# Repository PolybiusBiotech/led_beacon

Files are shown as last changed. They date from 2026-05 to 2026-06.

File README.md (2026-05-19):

# 🚨 LED Beacon 🚨

Upgrading cheap LED beacons for professional DMX/Art-Net stage control.

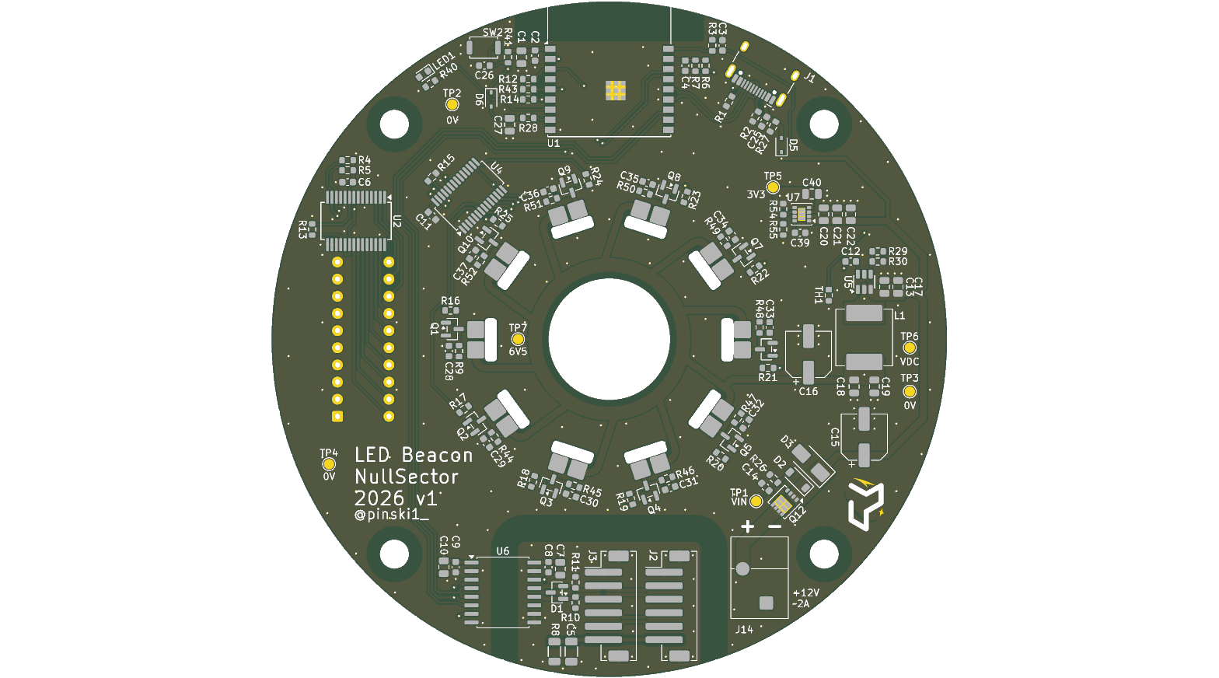
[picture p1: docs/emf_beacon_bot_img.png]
Hardware Render - Bottom


## 🚀 Manufacturing Status
- **Design:** Completed
- **Prototyping:** In Progress
- **Production:** Pending

## 📋 Quick Specs
- **Power:** +12V ±30% @ 2A
- **LEDS:** 10x strings of 6 LEDs
- **MCU:** ESP32-C3-WROOM-02
- **Connectivity:** DMX512 via 5 pin XLRs and WiFi

## 📂 Project Structure
- `/hardware`: KiCAD project files (Version 9.0.7).
- `/firmware`: PlatformIO project (Arduino/ESP-IDF framework).
- `/mechanical`: 3D-printable housing (.STEP).
- `/docs`: Specification, schematics and design calculations.
<!-- test: for test scripts -->

## 🛠 Setup & Development

### Hardware
- **Library Dependencies:** All footprints/symbols are [local to the repo / use standard KiCAD libs].
- **CI/CD:** Schematics are automatically exported to `/docs` on every push.

### Firmware
1. Open the `/firmware` folder in **VS Code**.
2. Ensure the **PlatformIO** extension is installed.
3. Connect your hardware via USB C port and click **Upload**.

## 📝 User Guide

1. Apply power via DC connector, 12V ±30% from a 3A capable supply.
2. Attach to DMX chain with 2x XLR 5pin cables
   * If at the end of the bus use a terminator plug
3. Select a DMX address with the DIP switch
   * This light consumes 20 slots so avoid address above 492.
   * Ensure that this light is >20 slots away from the next lights.
4. Disable the WiFi AP with the DIP switch unless needed for diagnostics
5. Use your DMX controller to send packets on the DMX chain.
   * Slots 1 to 10 control the brightness per channel
     * `0x00` is off
     * `0xFF` is on
   * Slots 11 to 20 control the strobe effect per channel
     * `0x00` is fully on
     * `0x01` strobes at 0.2Hz
     * `0xFF` strobes at 20Hz
6. Enjoy!

---
*Commissioned for Null Sector for EMF Camp 2026.*

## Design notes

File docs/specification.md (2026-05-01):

# LED Beacon: Technical Specification

The goal is to create a PCB that allows cheap LED Beacons to be upgraded so they can be controlled with a typical stage lighting desk.

Using the [MoSCoW method](https://en.wikipedia.org/wiki/MoSCoW_method) to prioritise specifications.

## 1. Must Have
*   **10-Channel Control:** Independent PWM control for 10x 6.4V @ 0.3A LED strips.
*   **DMX512-A Input:** 5-pin XLR interface with 5kV galvanic isolation and TVS protection.
*   **Robust Power Input:** Operation between +12V DC ±30% (8.4V – 15.6V).
*   **Strobe Functionality:** Support for 0.2Hz to 20Hz strobe speeds via DMX512.
    *   `0x00`: Static ON
    *   `0x01`: 0.2Hz Strobe.
    *   `0xFF`: 30Hz Strobe.
*   **Gamma Correction:** Implementation of a gamma brightness curve for human-eye linearity of LED PWM.
*   **Weatherproof Connections:** IP65/67 connectors suitable for outdoor festival use.

## 2. Should Have
*   **ESP32 Core:** Use of an ESP32 microcontroller for primary logic and timing.
*   **Fail-Safe Biasing:** Hardware biasing to ensure the DMX bus stays in a known state if the signal is lost.
*   **Isolation:** 5kV Galvanic Isolation between DMX bus and logic.
*   **Protection:** TVS Diode arrays on all data lines.
*   **Stability:** Active fail-safe biasing to prevent flickering on floating data lines.
*   **JLC-Optimized BOM:** Design utilizing "Basic" parts from the JLCPCB library to meet a £15-20 per unit (in batches of 25x) target.
*   **Enclosure:** Make use of the original beacons parts as much as possible.
*   **Thermal:** Designed for passive cooling at 100% duty cycle across all channels.

## 3. Could Have
*   **Art-Net Support:** Connectivity via RJ45 (Ethernet) to allow for modern lighting network integration.
*   **OTA Updates:** Ability to update firmware over Wi-Fi for last-minute festival bug fixes.
*   **On-board Thermal Monitoring:** Using the ESP32 internal sensor or a dedicated NTC to monitor the PCBA temperature during high-intensity strobe sequences.
*   **Enclosure:** Replace parts of the beacon with custom parts to aid assembly and robustness.
*   **Web Configuration Portal:** An ESP32-hosted captive portal to set DMX start addresses or Art-Net universes without reflashing.
*   **RDM Support:** Remote Device Management over the DMX line for remote addressing.

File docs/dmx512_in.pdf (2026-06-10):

X
Neutrik REAN: RRX5M-Z-002-0
XLR 5way | Pins
GND | 1
DMX+

2
DMX- | 3
AUX- | 4
AUX+ | 5
SHIELD | 6
Additional components
6 x #10 (heatshrink)

W
6x | 26 AWG | 10.0 cm
X:1:GND BK | J:1:GND
X:2:DMX+ RD | J:2:DMX+
X:3:DMX- WH | J:3:DMX-
X:4:AUX- YE | J:4:AUX-
X:5:AUX+ OG | J:5:AUX+
X:6:SHIELD GN | J:6:SHIELD

J
JST: PHR-6
JST PH 6way | Housing | 6-pin 1 | GND 2 | DMX+ 3 | DMX- 4 | AUX- 5 | AUX+ 6 | SHIELD

Additional components
6 x #3 (Crimp)

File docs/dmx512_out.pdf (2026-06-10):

X
Neutrik REAN: RRX5F-Z-002-0
XLR 5way | Socket
GND | 1
DMX+

2
DMX- | 3
AUX- | 4
AUX+ | 5
Additional components
5 x #9 (heatshrink)

W
5x | 26 AWG | 10.0 cm
X:1:GND BK | J:1:GND
X:2:DMX+ RD | J:2:DMX+
X:3:DMX- WH | J:3:DMX-
X:4:AUX- YE | J:4:AUX-
X:5:AUX+ OG | J:5:AUX+

J
JST: PHR-6
JST PH 6way | Housing | 6-pin 1 | GND 2 | DMX+ 3 | DMX- 4 | AUX- 5 | AUX+ 6 | NC

Additional components
5 x #3 (Crimp)

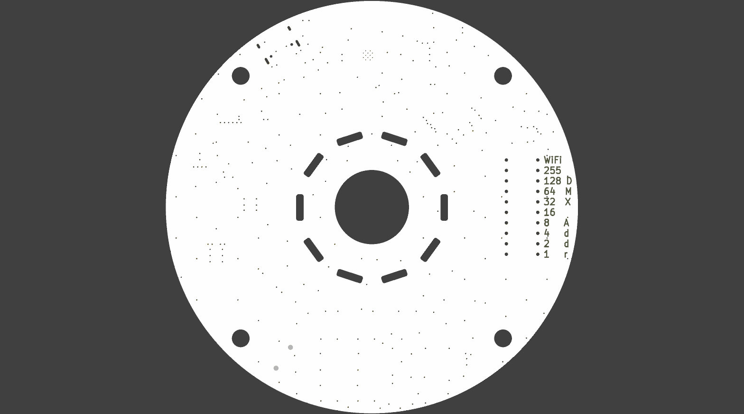
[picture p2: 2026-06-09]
docs/emf_beacon_top_img.png

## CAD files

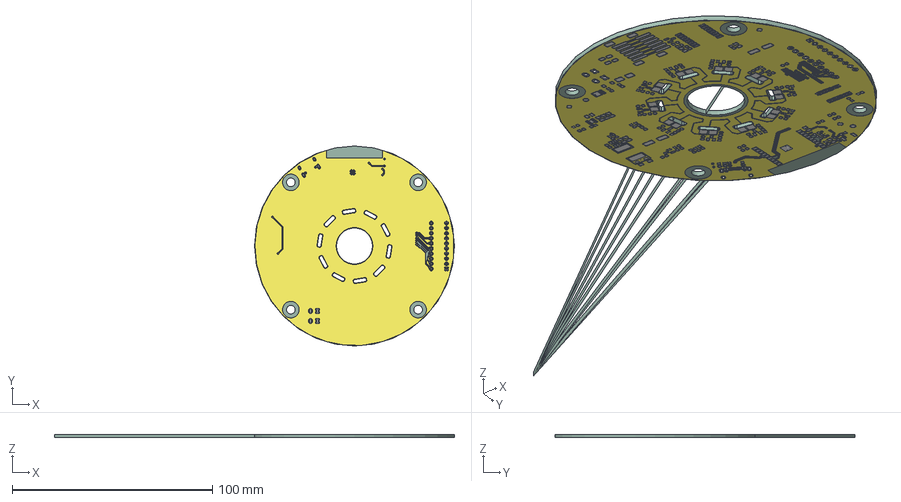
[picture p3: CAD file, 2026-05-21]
docs/emf_beacon_3d.step
200.0 x 150.0 x 1.59 mm
emf_beacon_copper
emf_beacon_pad
emf_beacon_via
emf_beacon_PCB

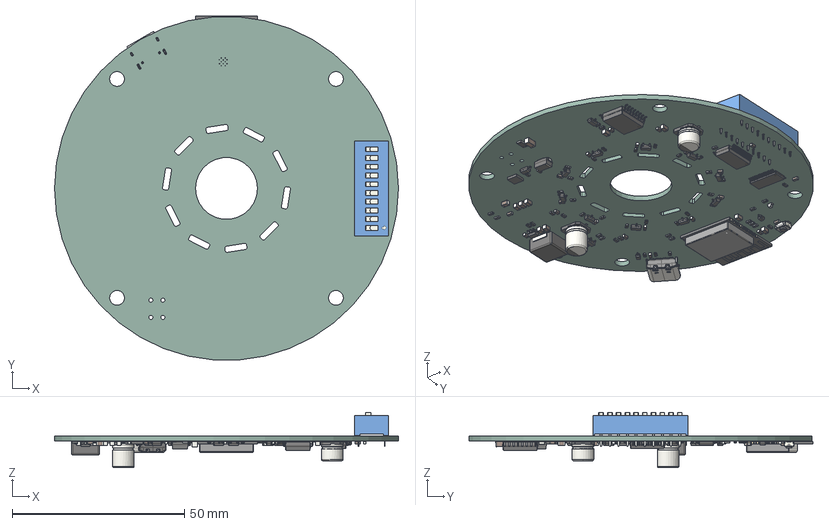
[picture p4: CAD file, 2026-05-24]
hardware/emf_beacon_2025-05-23.step
100.0 x 100.0 x 16.1 mm
SW_DIP_SPSTx10_Slide_9.78x27.58mm_W7.62mm_P2.54mm
C_0805_2012Metric x 12
R_0603_1608Metric x 47
SOIC-16W_7.5x10.3mm_P1.27mm
SOT-23 x 12
C_0603_1608Metric x 22
LED_0603_1608Metric
ESP32-C3-WROOM-02
L_Vishay_IHLP-3232
D_SOD-323 x 2
CP_Elec_6.3x7.7
SW_Push_SPST_NO_Alps_SKRK
SOT-23-6
R_1206_3216Metric
CP_Elec_6.3x5.7
USB_C_Receptacle_GCT_USB4105-xx-A_16P_TopMnt_Horizontal
C_1206_3216Metric
D_SMA
SSOP-28_5.3x10.2mm_P0.65mm
Diodes_PowerDI3333-8
TSSOP-28_4.4x9.7mm_P0.65mm
D_SOD-123
emf_beacon_PCB

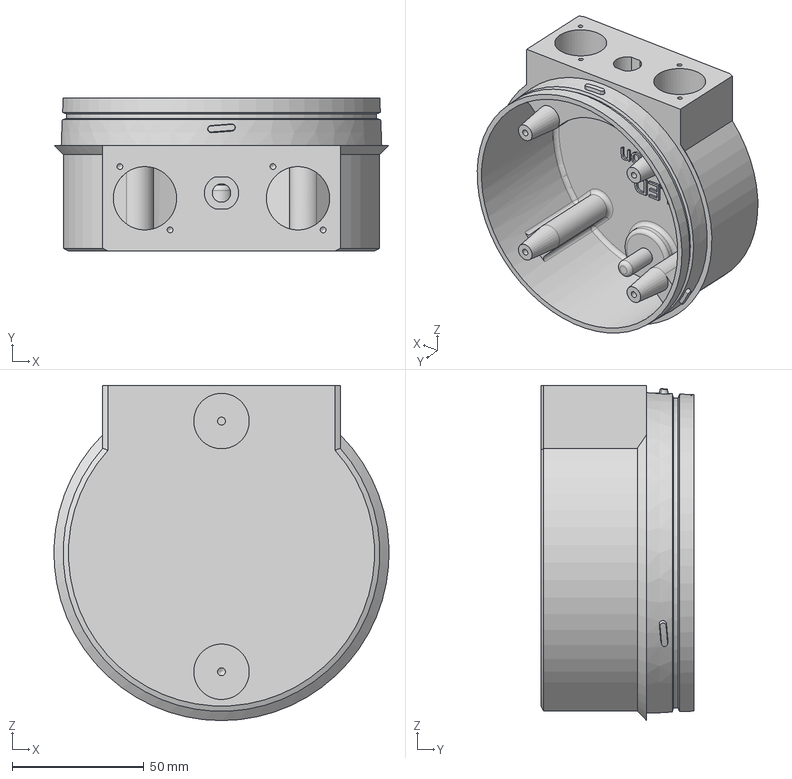
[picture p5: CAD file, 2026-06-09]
mechanical/3D Printed Base v17.step
126.9 x 58.0 x 127.0 mm

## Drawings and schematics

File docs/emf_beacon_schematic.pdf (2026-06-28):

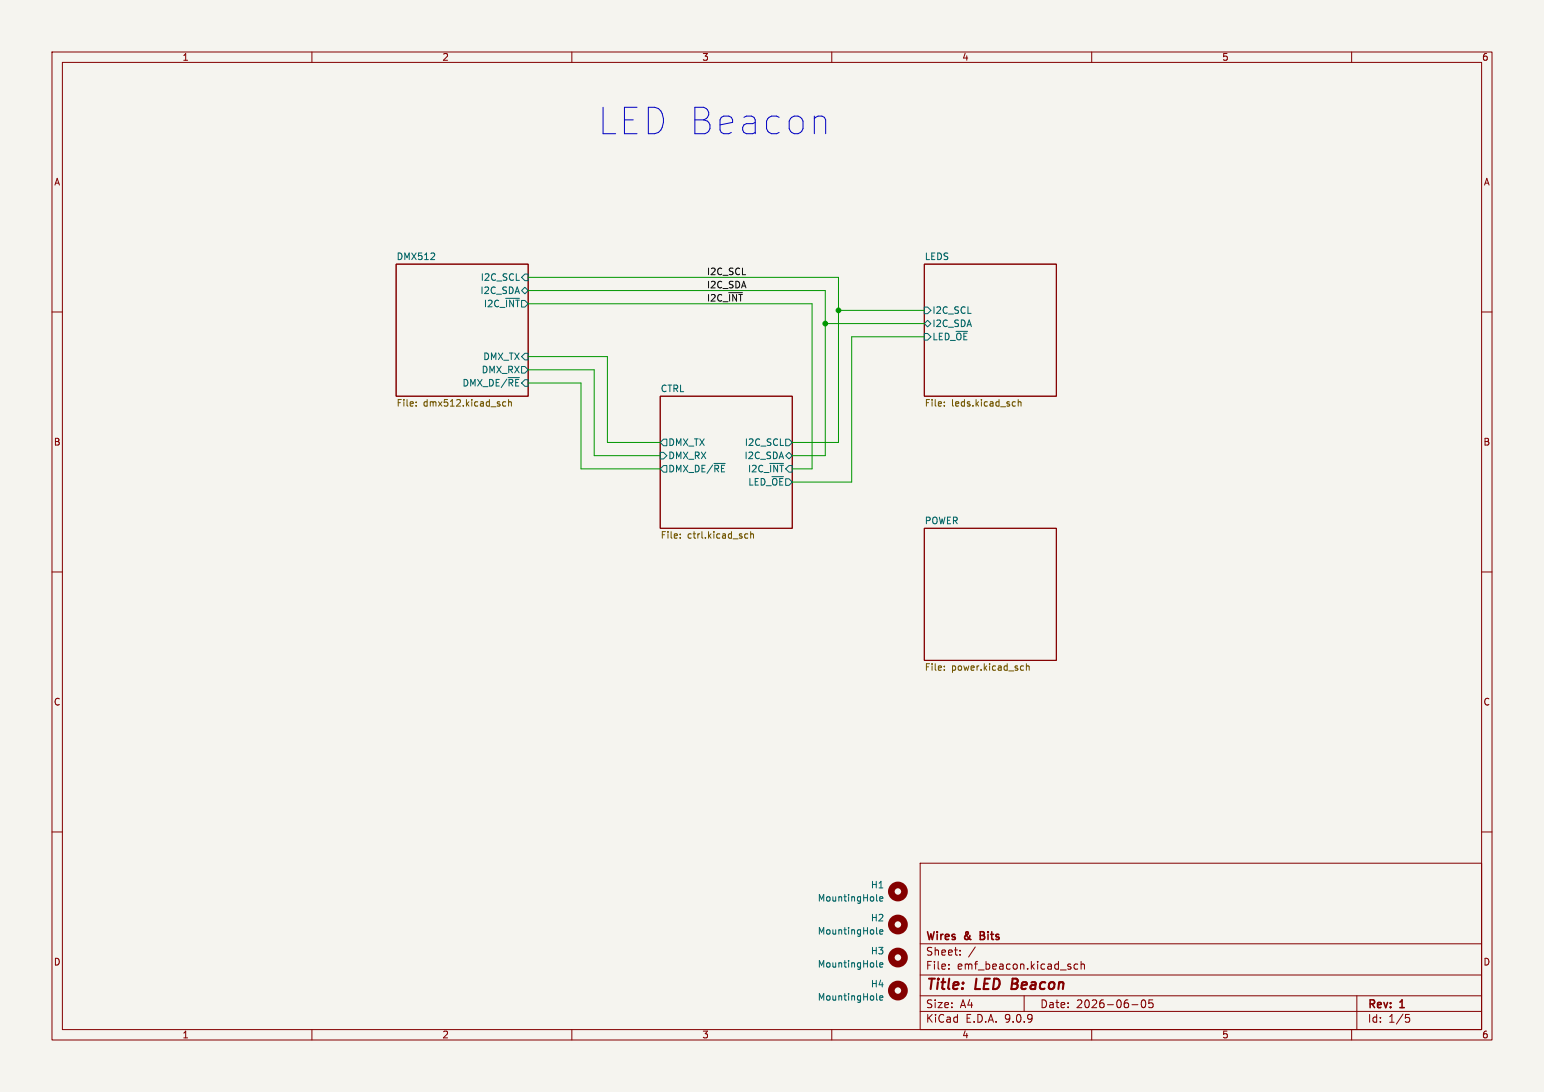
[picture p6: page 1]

Id: 1/5 Title: LED Beacon

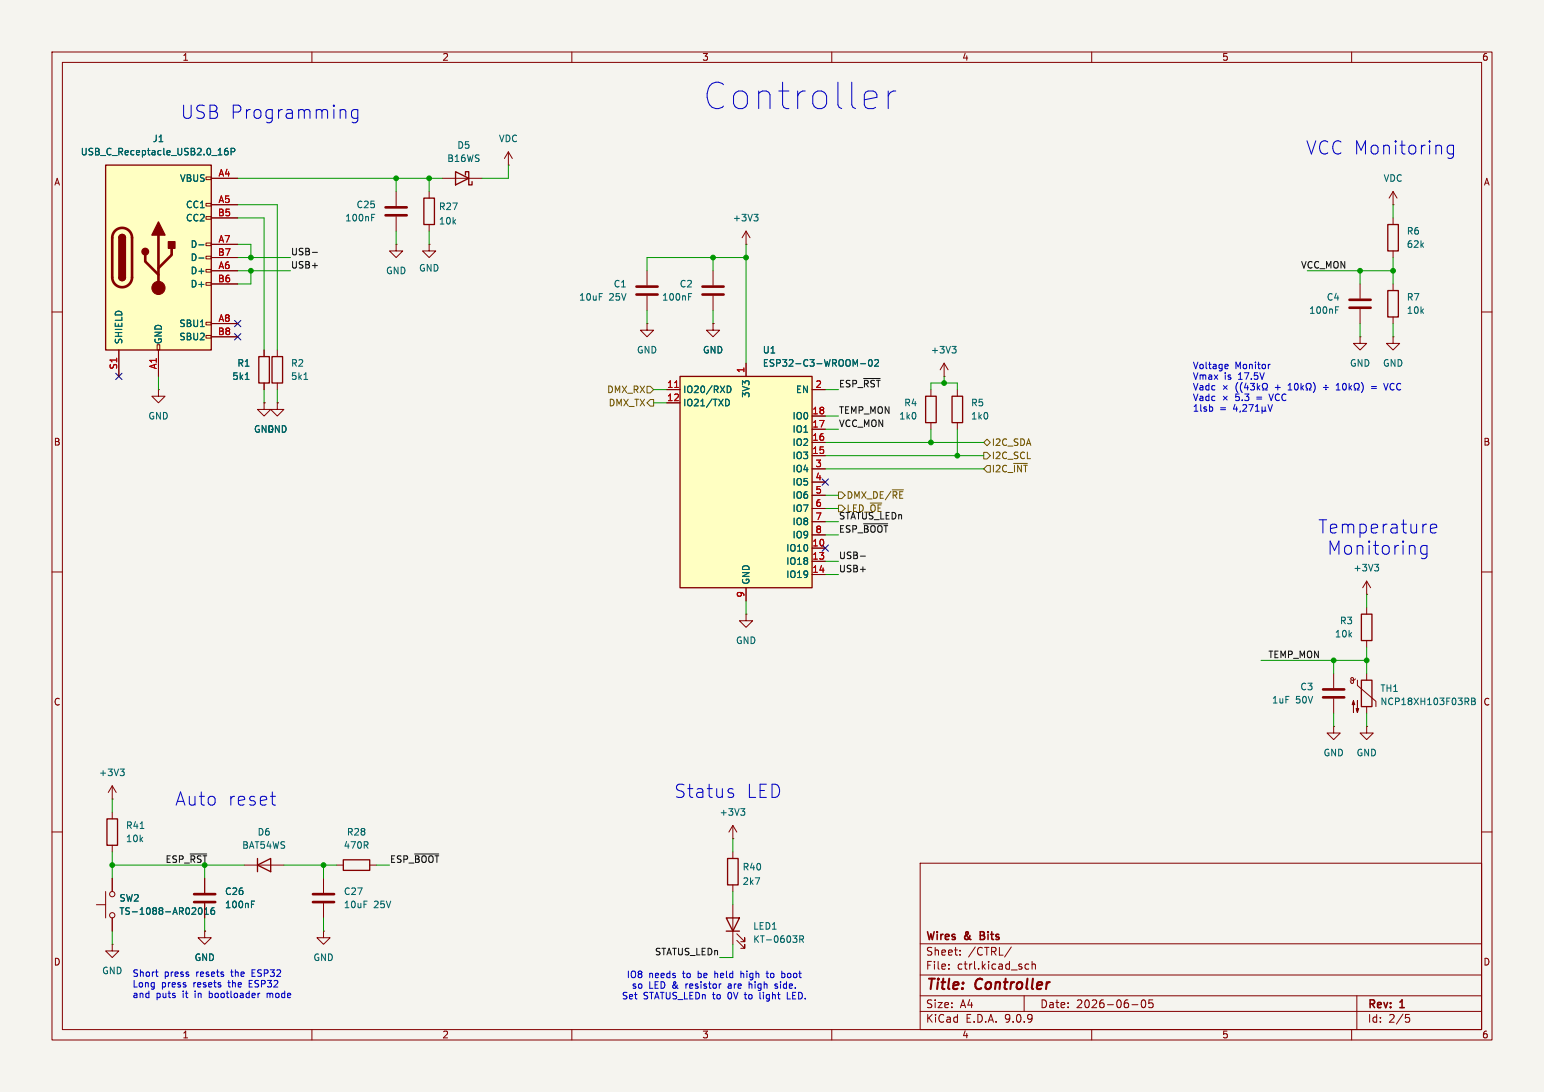
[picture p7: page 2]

Voltage Monitor Vmax is 17.5V

Vadc þÿ×þÿ((43k©+ þÿ10k©) þÿ÷þÿ10k©) = VCC
Vadc þÿ×5.3 = VCC
1lsb = þÿ4,271¼V

Short press resets the ESP32
Long press resets the ESP32

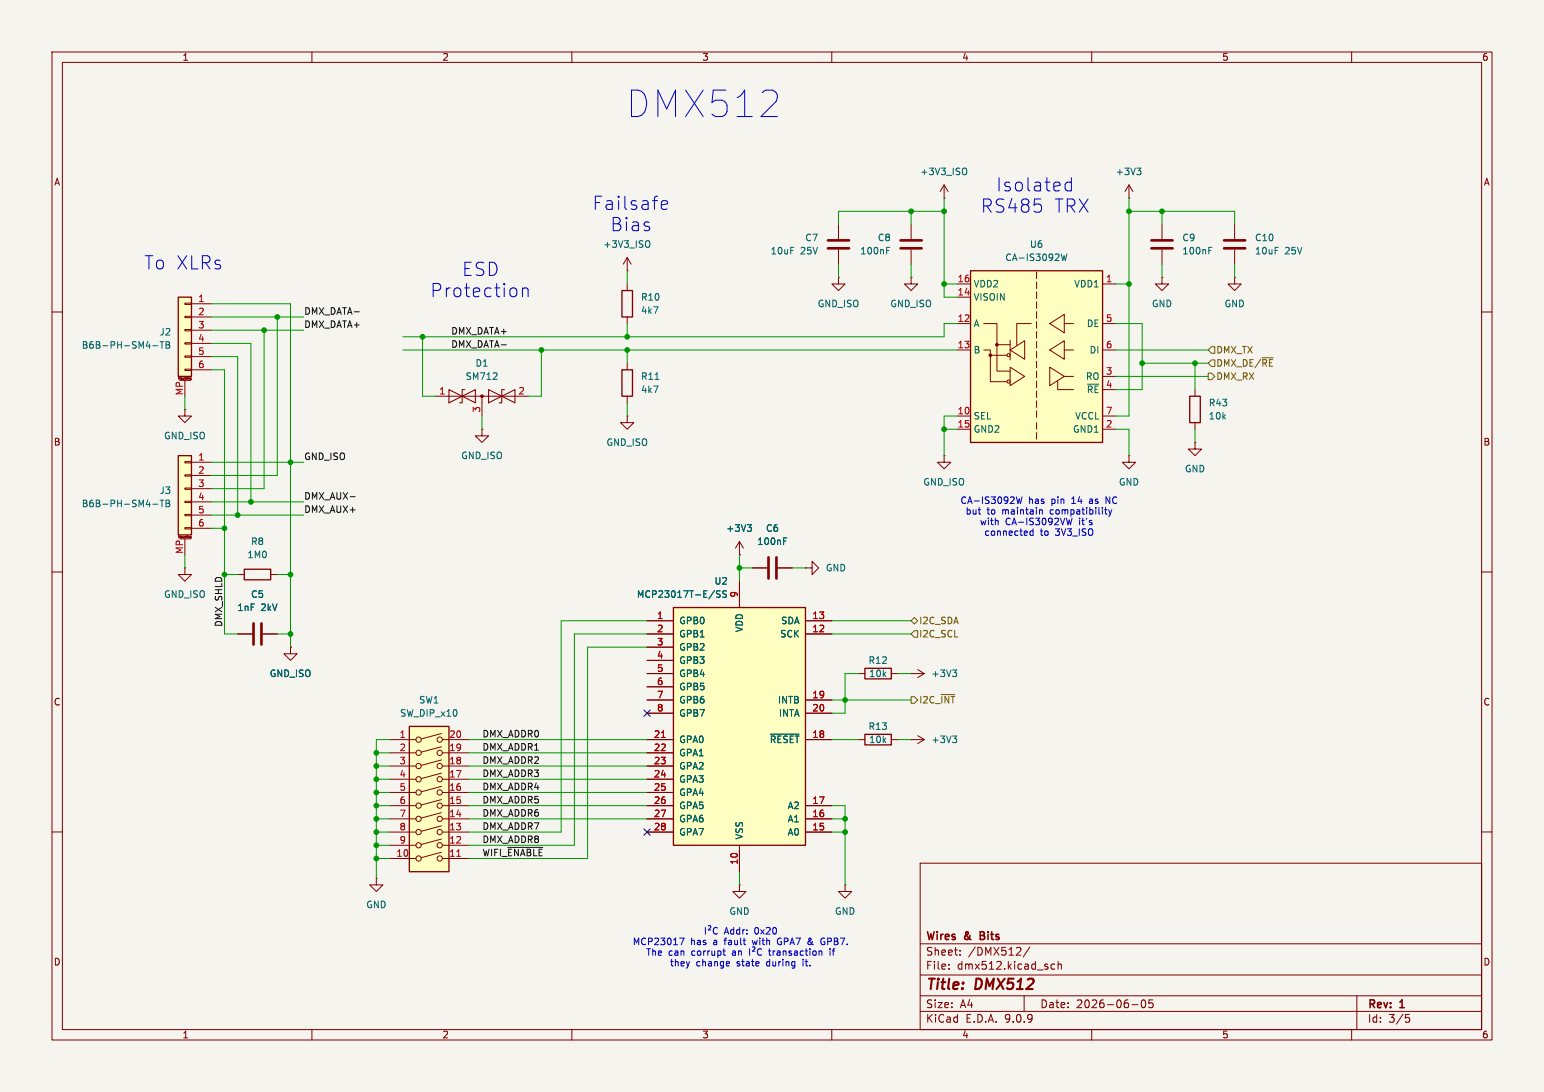
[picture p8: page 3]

they change state during it. Failsafe
Bias

9 VSS 10 GPB0 1 GPB1 2 GPB2 3 GPB3 4 GPB4 5 GPB5 6 GPB6 7 GPB7 8 GPA0 21 GPA1 22 GPA2 23 GPA3 24 GPA4 25 GPA5 26 GPA6 27 GPA7 28 U2 MCP23017T-E/SS GND GND

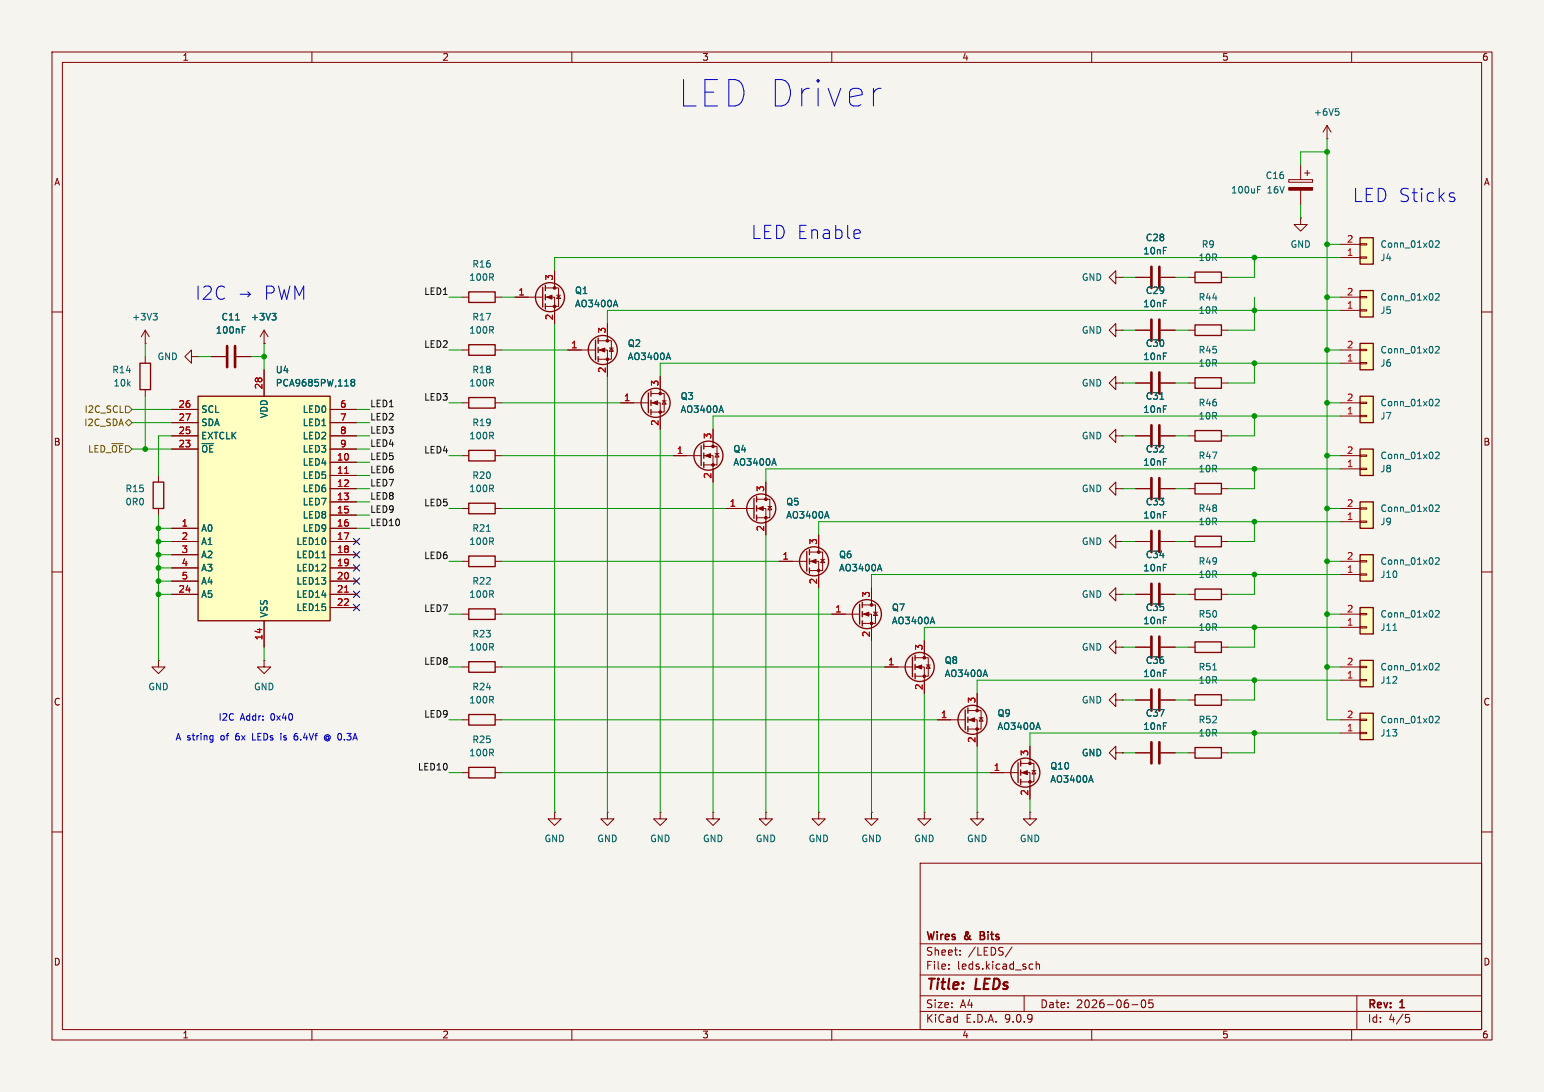
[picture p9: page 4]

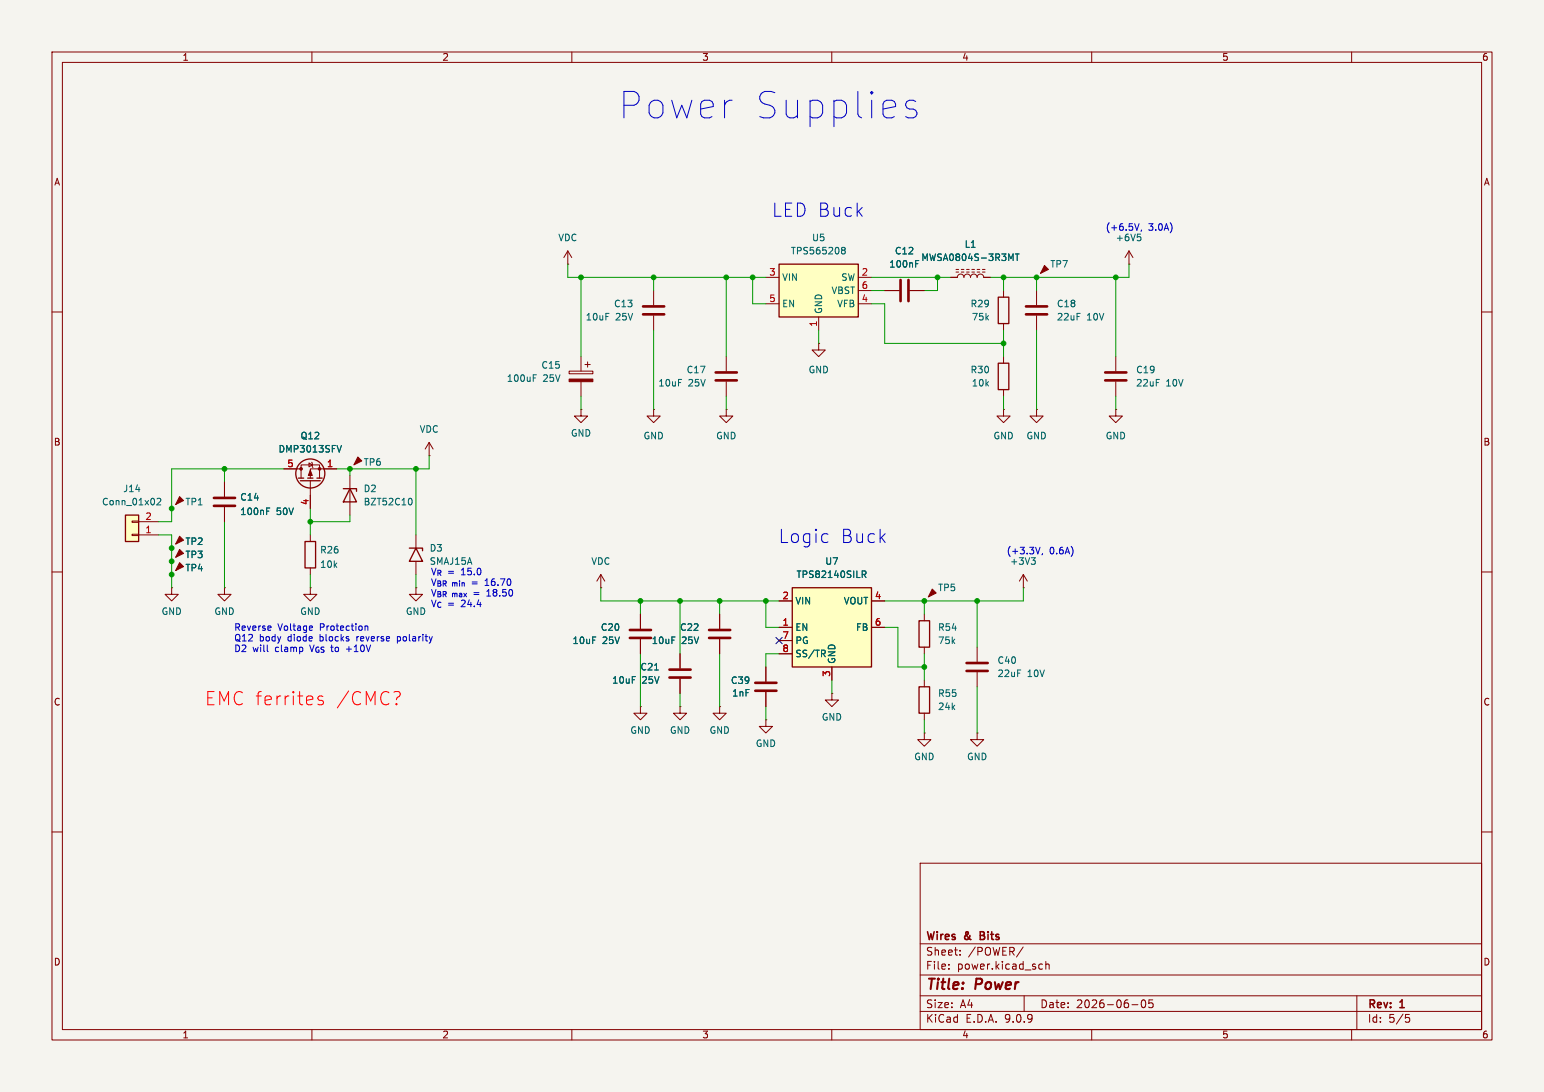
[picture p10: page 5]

1 SW 2 VBST 6 VFB 4 U5 TPS565208 GND GND

V_{R}= 15.0 V_{BR min} = 16.70 V_{BR max} = 18.50 V_{C}= 24.4

Reverse Voltage Protection Q12 body diode blocks reverse polarity D2 will clamp V_{GS} to +10V

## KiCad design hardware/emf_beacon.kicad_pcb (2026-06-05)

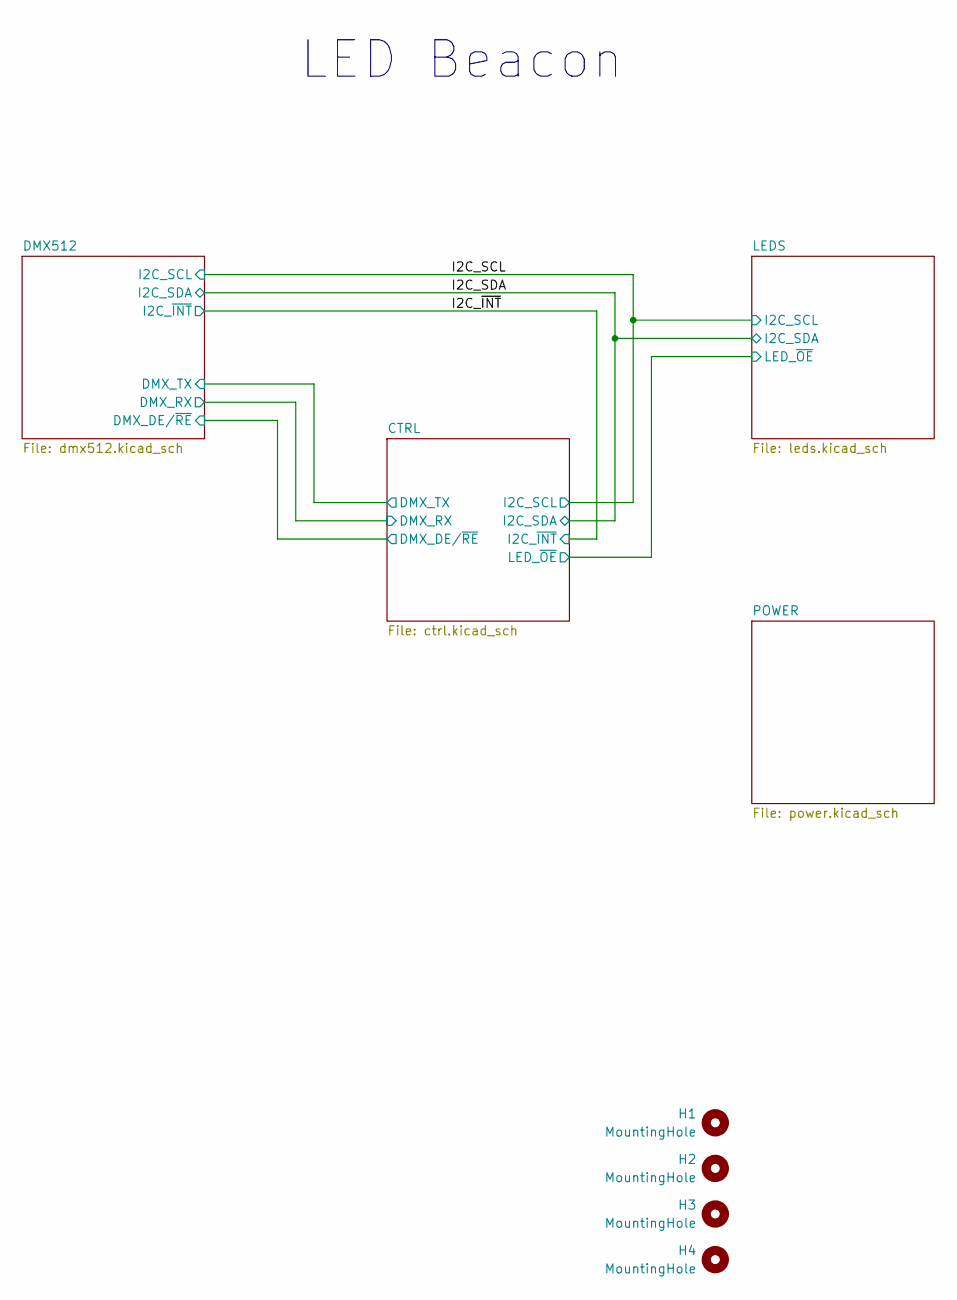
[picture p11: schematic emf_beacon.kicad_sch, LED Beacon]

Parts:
H1, H2, H3, H4: MountingHole; MountingHole_4.3mm_M4

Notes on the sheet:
LED Beacon

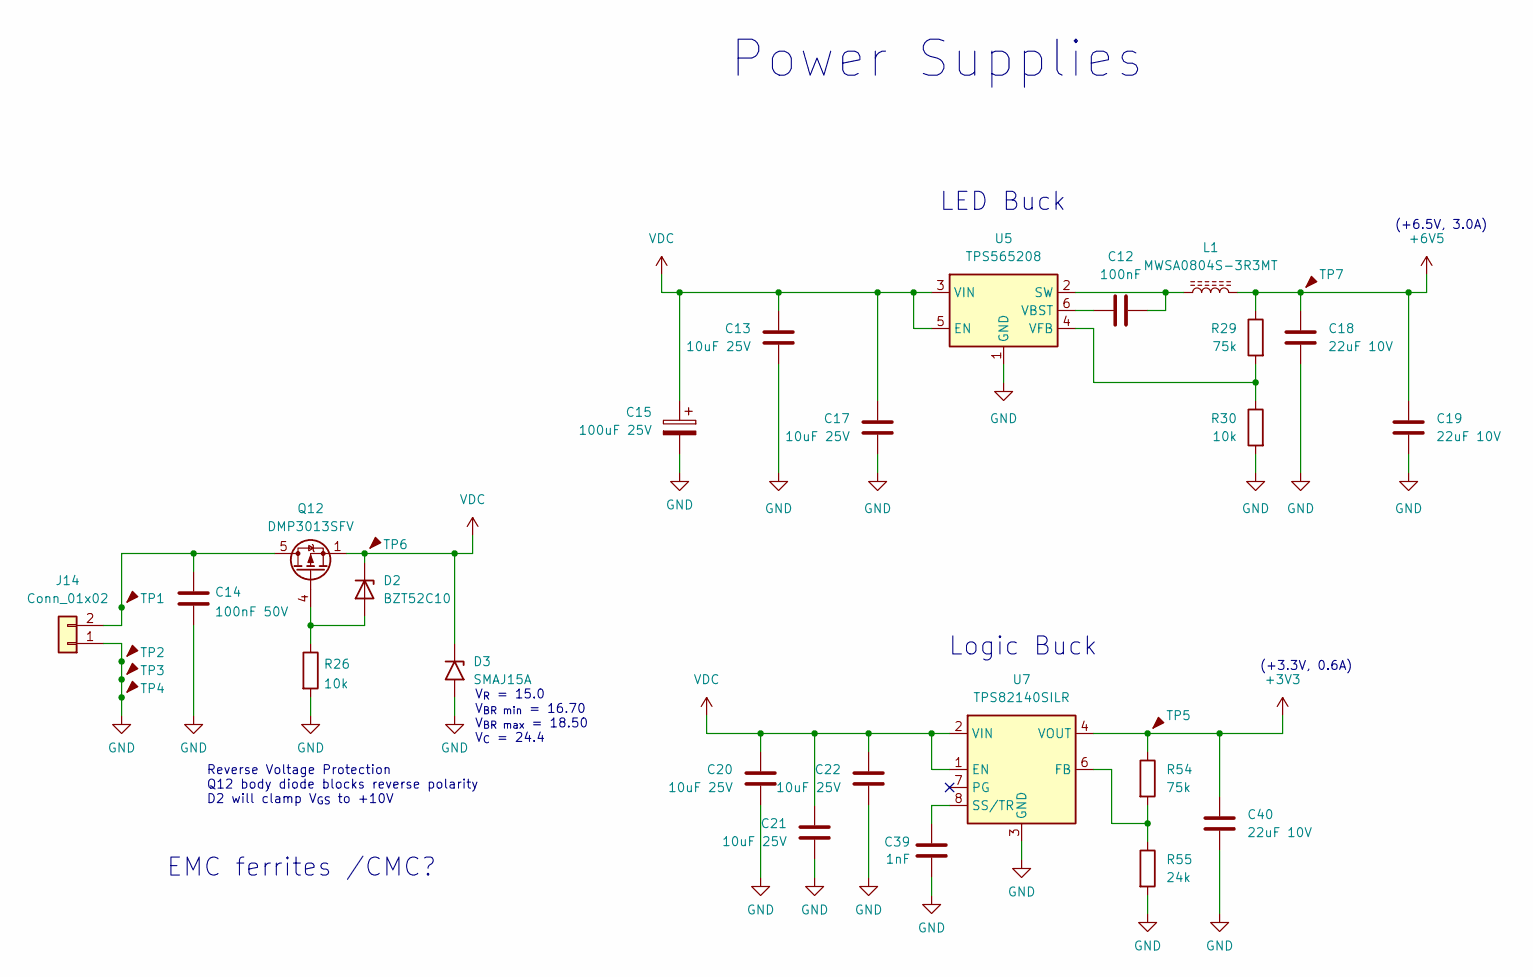
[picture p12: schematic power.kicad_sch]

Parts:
C12: 100nF; C_0603_1608Metric; LCSC C14663
C13, C17, C20, C21, C22: 10uF 25V; C_0805_2012Metric; LCSC C15850
C14: 100nF 50V; C_0603_1608Metric; LCSC C14663
C15: 100uF 25V; CP_Elec_6.3x7.7; LCSC C267469
C18, C19: 22uF 10V; C_0805_2012Metric; LCSC C45783
C39: 1nF; C_0603_1608Metric; Voltage 50V; LCSC C1588
C40: 22uF 10V; C_0805_2012Metric; Voltage 10V; LCSC C45783
D2: BZT52C10; D_SOD-123; LCSC C19077408
D3: SMAJ15A; D_SMA; LCSC C19077535
J14: Conn_01x02; MX250-3.5-02P-A-GY01-Cu-A; LCSC C7467028
L1: MWSA0804S-3R3MT; L_Vishay_IHLP-3232; LCSC C17700166
Q12: DMP3013SFV; Diodes_PowerDI3333-8; LCSC C49452326
R26, R30: 10k; R_0603_1608Metric; LCSC C25804
R29, R54: 75k; R_0603_1608Metric; LCSC C23242
R55: 24k; R_0603_1608Metric; LCSC C23352
TP1, TP2, TP3, TP4, TP5, TP6, TP7: TestPoint; TestPoint_Pad_D1.5mm
U5: TPS565208; SOT-23-6; LCSC C2650336
U7: TPS82140SILR; Texas_SIL0008D_MicroSiP-8-1EP_2.8x3mm_P0.65mm_EP1.1x1.9mm; LCSC C544385

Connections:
+3V3: C40.1, R54.1, TP5.1, U7.4 (VOUT), U7.5 (VOUT); also elsewhere on the board
+6V5: C18.1, C19.1, L1.2, R29.1, TP7.1; also elsewhere on the board
GND: C13.2, C14.2, C15.2, C17.2, C18.2, C19.2, C20.2, C21.2, C22.2, C39.2, C40.2, D3.2 (A2), J14.1, R26.2, R30.2, R55.2, TP2.1, TP3.1, TP4.1, U5.1 (GND), U7.3 (GND), U7.9 (GND); also elsewhere on the board
unnamed: D2.2 (A), Q12.4 (G), R26.1
unnamed: C14.1, J14.2, Q12.5 (D), TP1.1
unnamed: C12.2, L1.1, U5.2 (SW)
unnamed: C12.1, U5.6 (VBST)
unnamed: R29.2, R30.1, U5.4 (VFB)
unnamed: R54.2, R55.1, U7.6 (FB)
unnamed: C39.1, U7.8 (SS/TR)
VDC: C13.1, C15.1, C17.1, C20.1, C21.1, C22.1, D2.1 (K), D3.1 (A1), Q12.1 (S), Q12.2 (S), Q12.3 (S), TP6.1, U5.3 (VIN), U5.5 (EN), U7.1 (EN), U7.2 (VIN); also elsewhere on the board

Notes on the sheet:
LED Buck
Power Supplies
V_{R} = 15.0 V_{BR min} = 16.70 V_{BR max} = 18.50 V_{C} = 24.4
Logic Buck
(+6.5V, 3.0A)
EMC ferrites /CMC?
Reverse Voltage Protection Q12 body diode blocks reverse polarity D2 will clamp V_{GS} to +10V
(+3.3V, 0.6A)

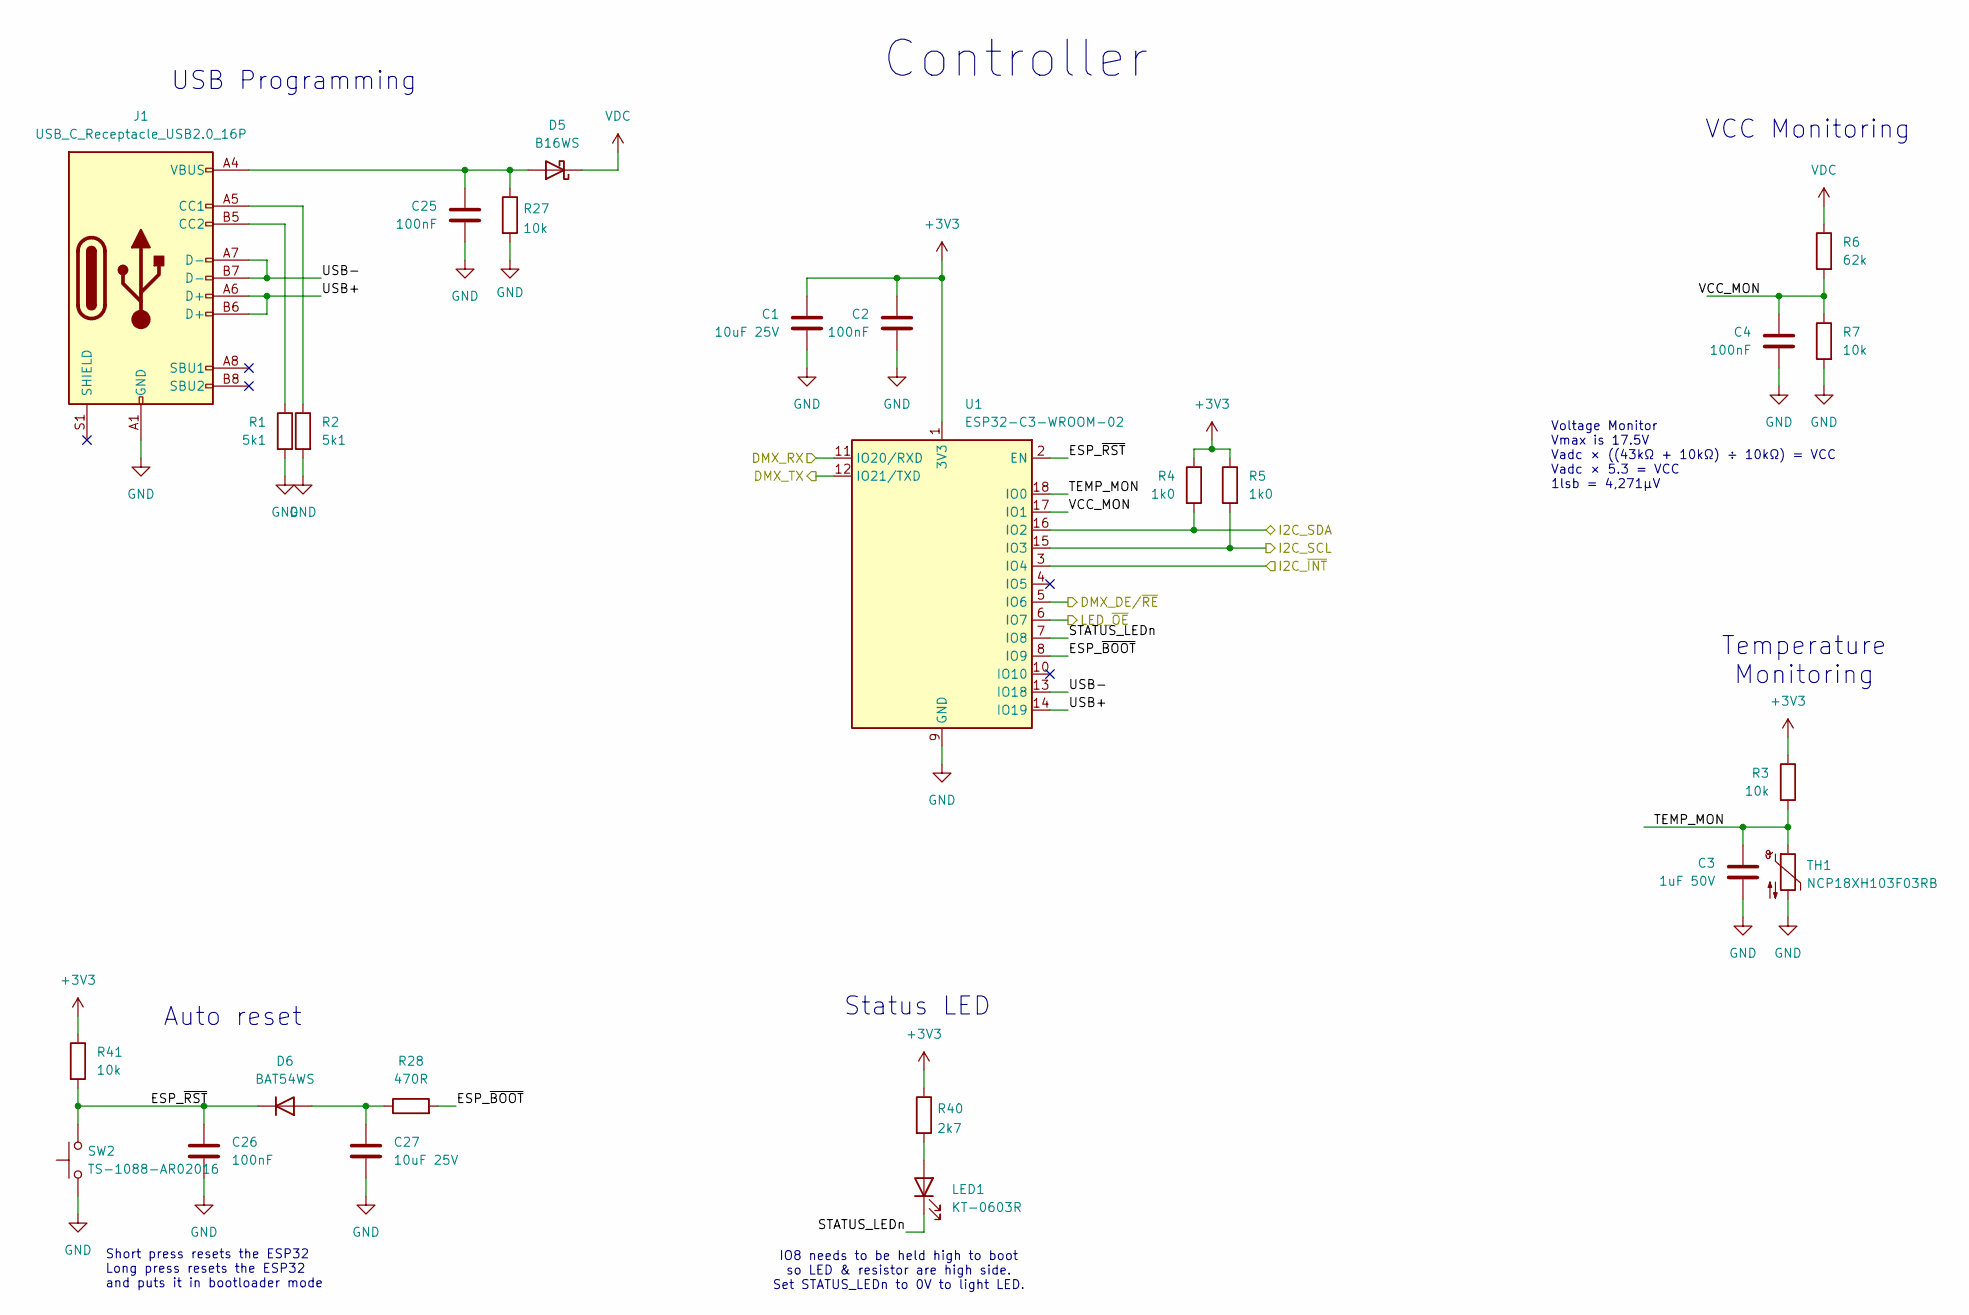
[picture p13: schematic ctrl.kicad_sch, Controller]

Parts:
C1, C27: 10uF 25V; C_0805_2012Metric; LCSC C15850
C2, C4, C25, C26: 100nF; C_0603_1608Metric; LCSC C14663
C3: 1uF 50V; C_0603_1608Metric; LCSC C15849
D5: B16WS; D_SOD-323; LCSC C7420327
D6: BAT54WS; D_SOD-323; LCSC C7502694
J1: USB_C_Receptacle_USB2.0_16P; USB_C_Receptacle_HCTL_HC-TYPE-C-16P-01A; LCSC C393939
LED1: KT-0603R; LED_0603_1608Metric; LCSC C2286
R1, R2: 5k1; R_0603_1608Metric; LCSC C23186
R3, R7, R27, R41: 10k; R_0603_1608Metric; LCSC C25804
R4, R5: 1k0; R_0603_1608Metric; LCSC C21190
R6: 62k; R_0603_1608Metric; LCSC C23221
R28: 470R; R_0603_1608Metric; LCSC C23179
R40: 2k7; R_0603_1608Metric; LCSC C13167
SW2: TS-1088-AR02016; SW_Push_SPST_NO_Alps_SKRK; LCSC C720477
TH1: NCP18XH103F03RB; R_0603_1608Metric; MPN NCP18XH103F03RB; LCSC C13564
U1: ESP32-C3-WROOM-02; LCSC C2934560

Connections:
+3V3: C1.1, C2.1, R3.1, R4.1, R5.1, R40.1, R41.1, U1.1 (3V3); also elsewhere on the board
/CTRL/DMX_DE/~RE: U1.5 (IO6); also elsewhere on the board
/CTRL/DMX_RX: U1.11 (IO20/RXD); also elsewhere on the board
/CTRL/DMX_TX: U1.12 (IO21/TXD); also elsewhere on the board
/CTRL/ESP_~BOOT: R28.2, U1.8 (IO9)
/CTRL/ESP_~RST: C26.1, D6.1 (K), R41.2, SW2.2, U1.2 (EN)
/CTRL/LED_~OE: U1.6 (IO7); also elsewhere on the board
/CTRL/STATUS_LEDn: LED1.1 (K), U1.7 (IO8)
/CTRL/TEMP_MON: C3.1, R3.2, TH1.1, U1.18 (IO0)
/CTRL/USB+: J1.A6 (D+), J1.B6 (D+), U1.14 (IO19)
/CTRL/USB-: J1.A7 (D-), J1.B7 (D-), U1.13 (IO18)
/CTRL/VCC_MON: C4.1, R6.2, R7.1, U1.17 (IO1)
/I2C_SCL: R5.2, U1.15 (IO3); also elsewhere on the board
/I2C_SDA: R4.2, U1.16 (IO2); also elsewhere on the board
/I2C_~INT: U1.3 (IO4); also elsewhere on the board
GND: C1.2, C2.2, C3.2, C4.2, C25.2, C26.2, C27.2, J1.A1 (GND), J1.A12 (GND), J1.B1 (GND), J1.B12 (GND), R1.2, R2.2, R7.2, R27.2, SW2.1, TH1.2, U1.9 (GND), U1.19 (GND); also elsewhere on the board
unnamed: C25.1, D5.2 (A), J1.A4 (VBUS), J1.A9 (VBUS), J1.B4 (VBUS), J1.B9 (VBUS), R27.1
unnamed: C27.1, D6.2 (A), R28.1
unnamed: J1.A5 (CC1), R2.1
unnamed: J1.B5 (CC2), R1.1
unnamed: LED1.2 (A), R40.2
VDC: D5.1 (K), R6.1; also elsewhere on the board

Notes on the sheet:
Auto reset
VCC Monitoring
Status LED
Short press resets the ESP32 Long press resets the ESP32 and puts it in bootloader mode
Temperature Monitoring
USB Programming
Controller
IO8 needs to be held high to boot so LED & resistor are high side. Set STATUS_LEDn to 0V to light LED.
Voltage Monitor Vmax is 17.5V Vadc × ((43kΩ + 10kΩ) ÷ 10kΩ) = VCC Vadc × 5.3 = VCC 1lsb = 4,271μV

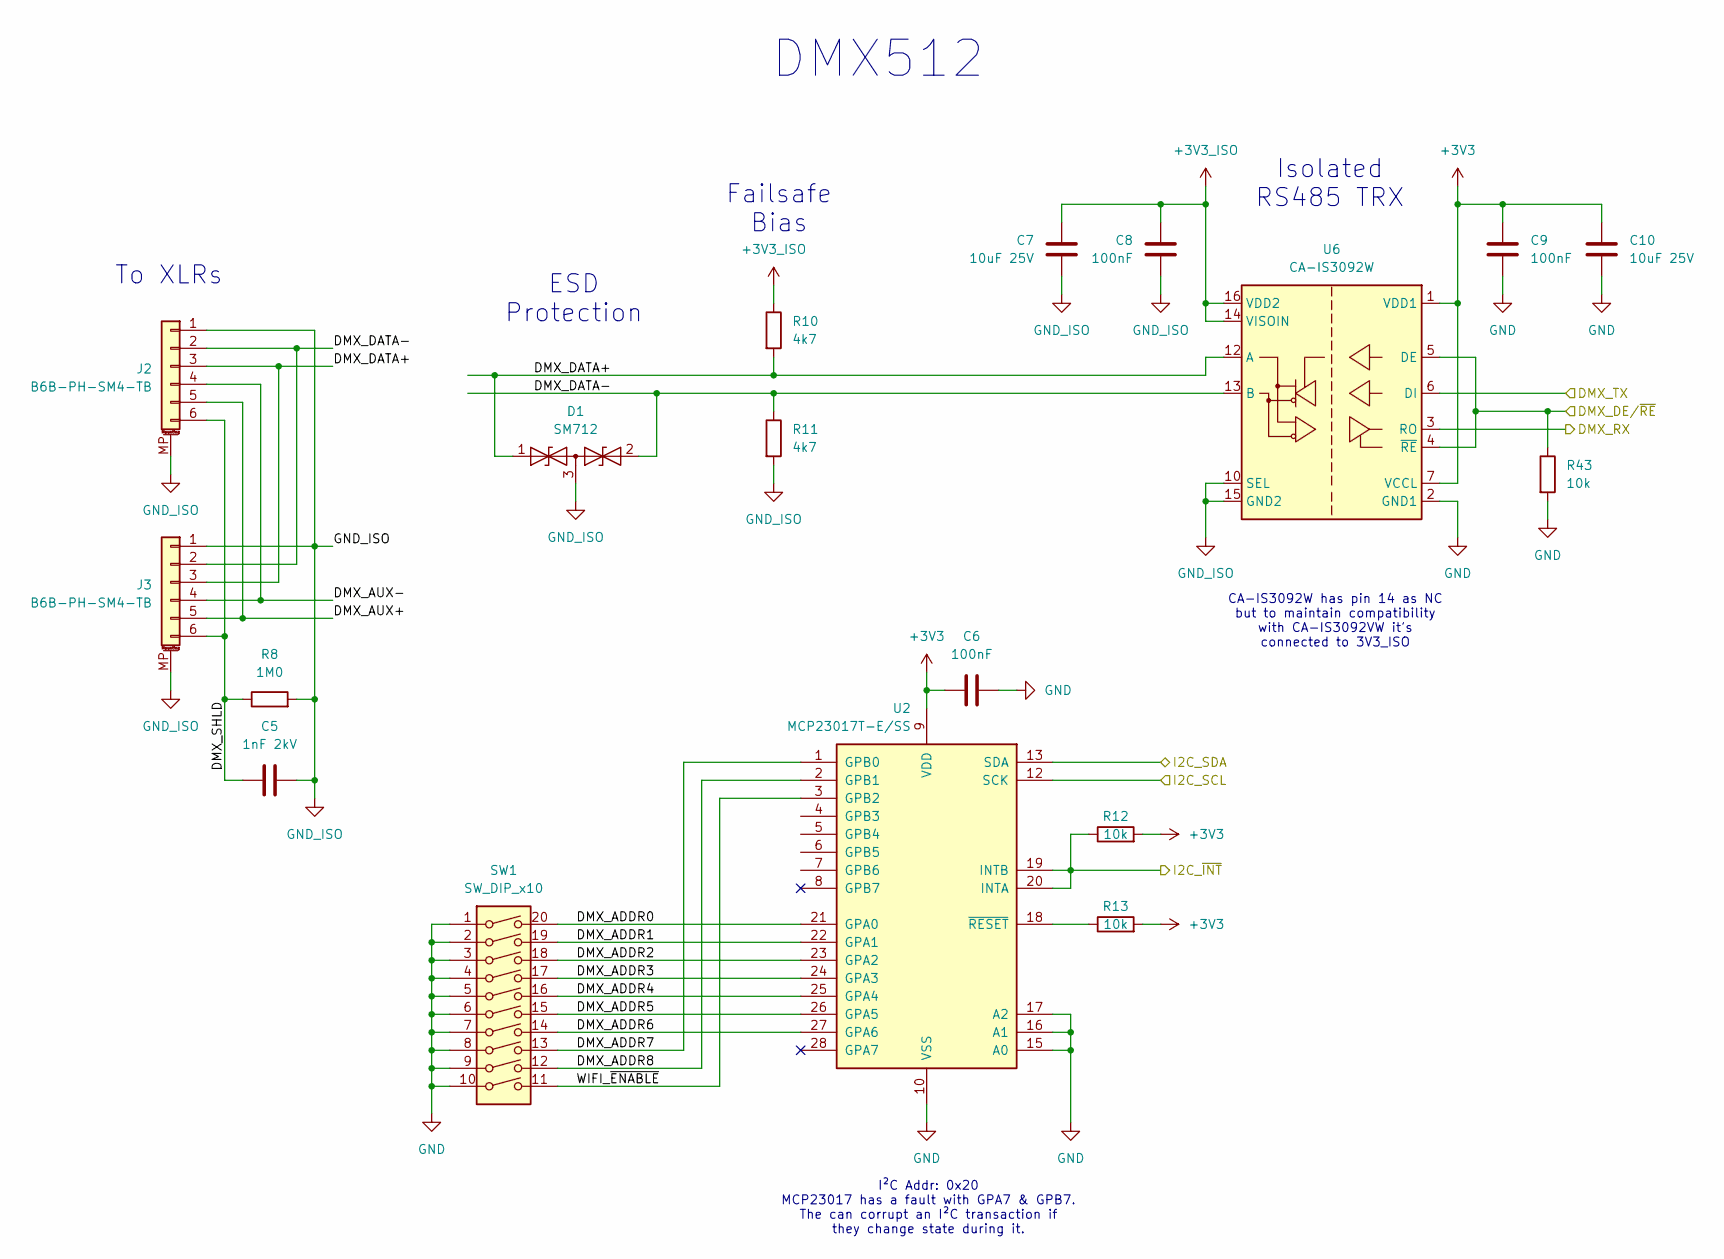
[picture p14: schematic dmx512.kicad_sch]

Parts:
C5: 1nF 2kV; C_1206_3216Metric; LCSC C9196
C6, C8, C9: 100nF; C_0603_1608Metric; LCSC C14663
C7, C10: 10uF 25V; C_0805_2012Metric; LCSC C15850
D1: SM712; SOT-23; LCSC C7420375
J2, J3: B6B-PH-SM4-TB; JST_PH_B6B-PH-SM4-TB_1x06-1MP_P2.00mm_Vertical; LCSC C471518
R8: 1M0; R_1206_3216Metric; LCSC C17927
R10, R11: 4k7; R_0603_1608Metric; LCSC C23162
R12, R13, R43: 10k; R_0603_1608Metric; LCSC C25804
SW1: SW_DIP_x10; SW_DIP_SPSTx10_Slide_9.78x27.58mm_W7.62mm_P2.54mm; LCSC C509577
U2: MCP23017T-E/SS; SSOP-28_5.3x10.2mm_P0.65mm; LCSC C558584
U6: CA-IS3092W; SOIC-16W_7.5x10.3mm_P1.27mm; LCSC C2890051

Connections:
+3V3: C6.2, C9.1, C10.1, R12.2, R13.2, U2.9 (VDD), U6.1 (VDD1), U6.7 (VCCL); also elsewhere on the board
+3V3_ISO: C7.1, C8.1, R10.1, U6.14 (VISOIN), U6.16 (VDD2)
/CTRL/DMX_DE/~RE: R43.1, U6.4 (~RE), U6.5 (DE); also elsewhere on the board
/CTRL/DMX_RX: U6.3 (RO); also elsewhere on the board
/CTRL/DMX_TX: U6.6 (DI); also elsewhere on the board
/DMX512/DMX_ADDR0: SW1.20, U2.21 (GPA0)
/DMX512/DMX_ADDR1: SW1.19, U2.22 (GPA1)
/DMX512/DMX_ADDR2: SW1.18, U2.23 (GPA2)
/DMX512/DMX_ADDR3: SW1.17, U2.24 (GPA3)
/DMX512/DMX_ADDR4: SW1.16, U2.25 (GPA4)
/DMX512/DMX_ADDR5: SW1.15, U2.26 (GPA5)
/DMX512/DMX_ADDR6: SW1.14, U2.27 (GPA6)
/DMX512/DMX_ADDR7: SW1.13, U2.1 (GPB0)
/DMX512/DMX_ADDR8: SW1.12, U2.2 (GPB1)
/DMX512/DMX_AUX+: J2.5, J3.5
/DMX512/DMX_AUX-: J2.4, J3.4
/DMX512/DMX_DATA+: D1.1 (A1), J2.3, J3.3, R10.2, U6.12 (A)
/DMX512/DMX_DATA-: D1.2 (A2), J2.2, J3.2, R11.1, U6.13 (B)
/DMX512/DMX_SHLD: C5.1, J2.6, J3.6, R8.1
/DMX512/WIFI_~ENABLE: SW1.11, U2.3 (GPB2)
/I2C_SCL: U2.12 (SCK); also elsewhere on the board
/I2C_SDA: U2.13 (SDA); also elsewhere on the board
/I2C_~INT: R12.1, U2.19 (INTB), U2.20 (INTA); also elsewhere on the board
GND: C6.1, C9.2, C10.2, R43.2, SW1.1, SW1.2, SW1.3, SW1.4, SW1.5, SW1.6, SW1.7, SW1.8, SW1.9, SW1.10, U2.10 (VSS), U2.15 (A0), U2.16 (A1), U2.17 (A2), U6.2 (GND1), U6.8 (GND1); also elsewhere on the board
GND_ISO: C5.2, C7.2, C8.2, D1.3 (common), J2.1, J2.MP (MountPin), J3.1, J3.MP (MountPin), R8.2, R11.2, U6.9 (GND2), U6.10 (SEL), U6.15 (GND2)
unnamed: R13.1, U2.18 (~RESET)

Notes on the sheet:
I²C Addr: 0x20 MCP23017 has a fault with GPA7 & GPB7. The can corrupt an I²C transaction if they change state during it.
Failsafe Bias
DMX512
CA-IS3092W has pin 14 as NC but to maintain compatibility with CA-IS3092VW it's connected to 3V3_ISO
To XLRs
ESD Protection
Isolated RS485 TRX

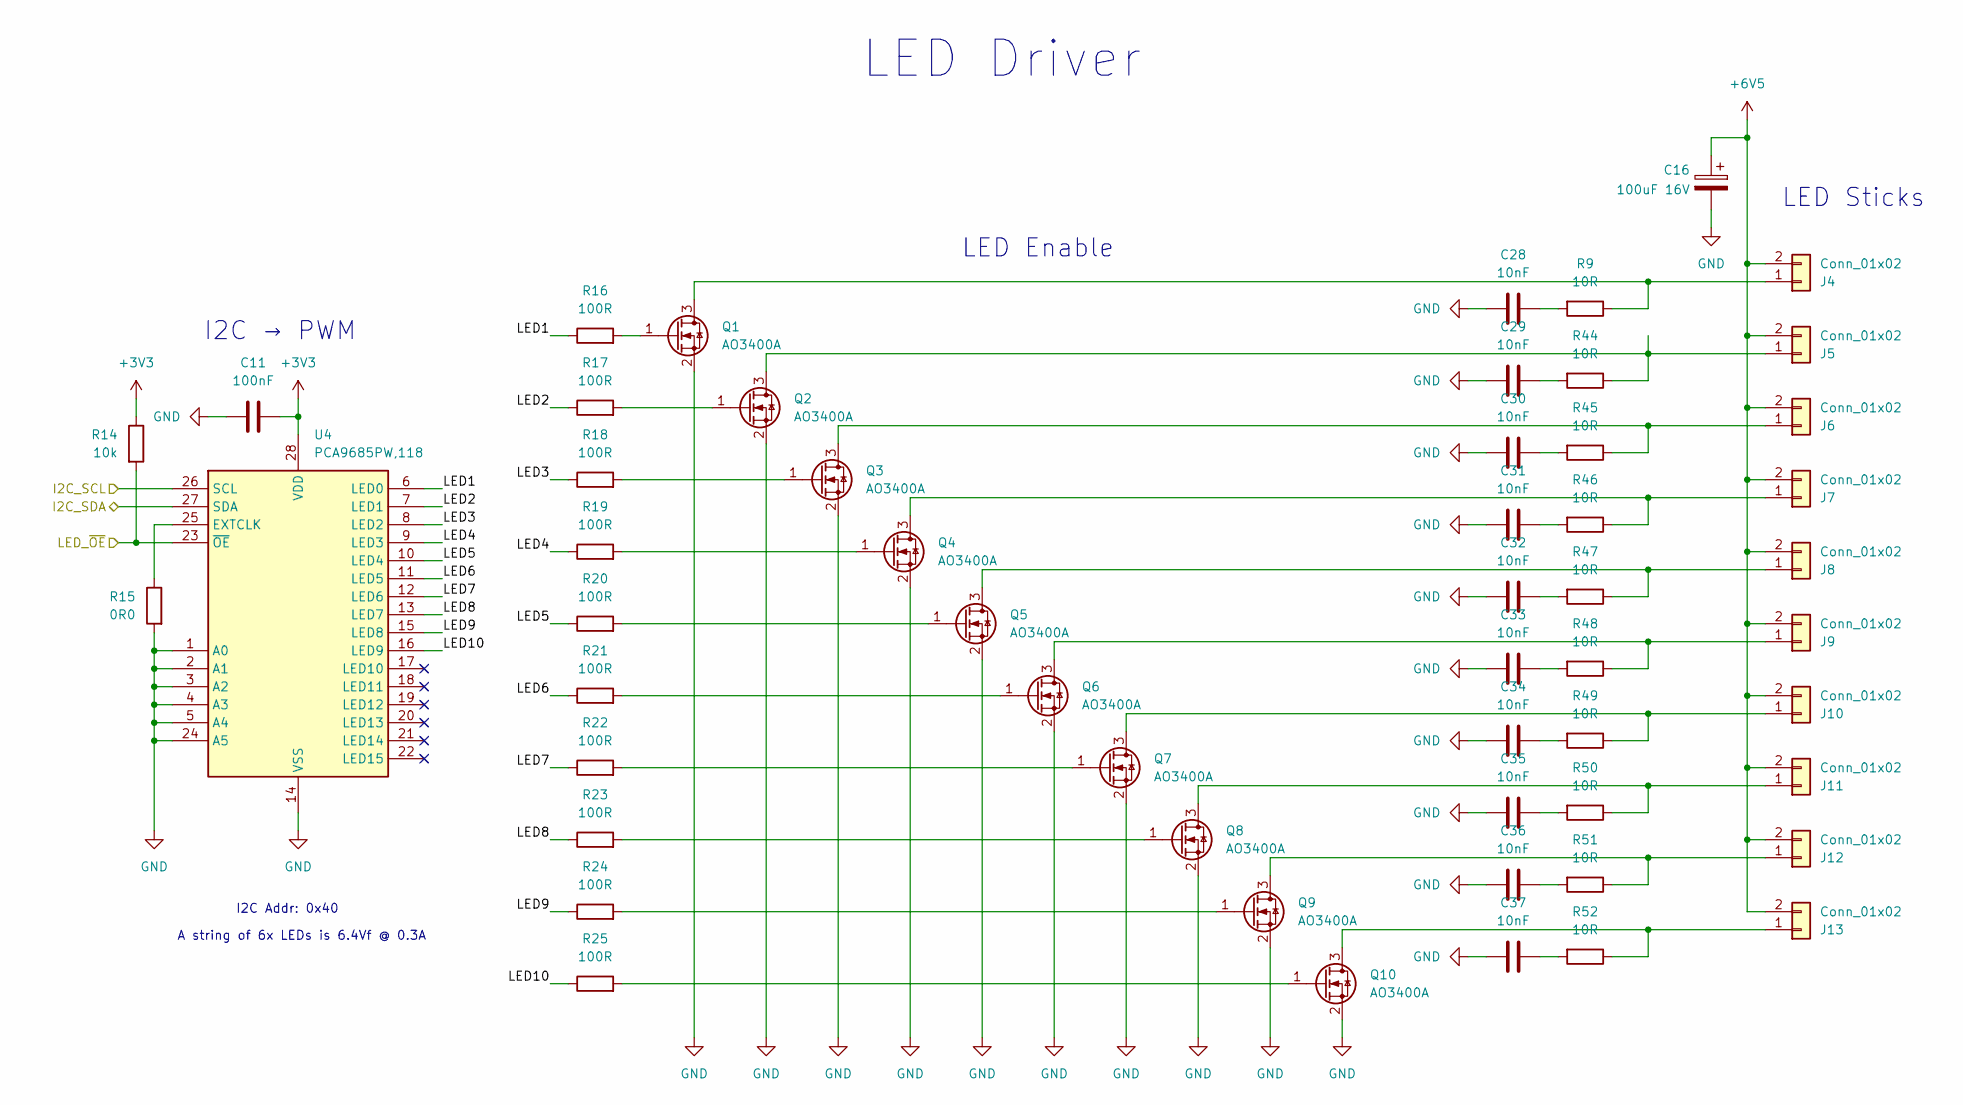
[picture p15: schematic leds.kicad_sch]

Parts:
C11: 100nF; C_0603_1608Metric; LCSC C14663
C16: 100uF 16V; CP_Elec_6.3x5.7; LCSC C3646798
C28, C29, C30, C31, C32, C33, C34, C35, C36, C37: 10nF; C_0603_1608Metric; LCSC C57112
J4, J5, J6, J7, J8, J9, J10, J11, J12, J13: Conn_01x02; LED_Stick
Q1, Q2, Q3, Q4, Q5, Q6, Q7, Q8, Q9, Q10: AO3400A; SOT-23; LCSC C20917
R9, R44, R45, R46, R47, R48, R49, R50, R51, R52: 10R; R_0603_1608Metric; LCSC C22859
R14: 10k; R_0603_1608Metric; LCSC C25804
R15: 0R0; R_0603_1608Metric; LCSC C21189
R16, R17, R18, R19, R20, R21, R22, R23, R24, R25: 100R; R_0603_1608Metric; LCSC C22775
U4: PCA9685PW,118; TSSOP-28_4.4x9.7mm_P0.65mm; LCSC C2678753

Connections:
+3V3: C11.2, R14.1, U4.28 (VDD); also elsewhere on the board
+6V5: C16.1, J4.2, J5.2, J6.2, J7.2, J8.2, J9.2, J10.2, J11.2, J12.2, J13.2; also elsewhere on the board
/CTRL/LED_~OE: R14.2, U4.23 (~OE); also elsewhere on the board
/I2C_SCL: U4.26 (SCL); also elsewhere on the board
/I2C_SDA: U4.27 (SDA); also elsewhere on the board
/LEDS/LED1: R16.1, U4.6 (LED0)
/LEDS/LED2: R17.1, U4.7 (LED1)
/LEDS/LED3: R18.1, U4.8 (LED2)
/LEDS/LED4: R19.1, U4.9 (LED3)
/LEDS/LED5: R20.1, U4.10 (LED4)
/LEDS/LED6: R21.1, U4.11 (LED5)
/LEDS/LED7: R22.1, U4.12 (LED6)
/LEDS/LED8: R23.1, U4.13 (LED7)
/LEDS/LED9: R24.1, U4.15 (LED8)
/LEDS/LED10: R25.1, U4.16 (LED9)
GND: C11.1, C16.2, C28.1, C29.1, C30.1, C31.1, C32.1, C33.1, C34.1, C35.1, C36.1, C37.1, Q1.2 (S), Q2.2 (S), Q3.2 (S), Q4.2 (S), Q5.2 (S), Q6.2 (S), Q7.2 (S), Q8.2 (S), Q9.2 (S), Q10.2 (S), R15.2, U4.1 (A0), U4.2 (A1), U4.3 (A2), U4.4 (A3), U4.5 (A4), U4.14 (VSS), U4.24 (A5); also elsewhere on the board
unnamed: C28.2, R9.2
unnamed: C29.2, R44.2
unnamed: C30.2, R45.2
unnamed: C31.2, R46.2
unnamed: C32.2, R47.2
unnamed: C33.2, R48.2
unnamed: C34.2, R49.2
unnamed: C35.2, R50.2
unnamed: C36.2, R51.2
unnamed: C37.2, R52.2
unnamed: J4.1, Q1.3 (D), R9.1
unnamed: J5.1, Q2.3 (D), R44.1
unnamed: J6.1, Q3.3 (D), R45.1
unnamed: J7.1, Q4.3 (D), R46.1
unnamed: J8.1, Q5.3 (D), R47.1
unnamed: J9.1, Q6.3 (D), R48.1
unnamed: J10.1, Q7.3 (D), R49.1
unnamed: J11.1, Q8.3 (D), R50.1
unnamed: J12.1, Q9.3 (D), R51.1
unnamed: J13.1, Q10.3 (D), R52.1
unnamed: Q1.1 (G), R16.2
unnamed: Q2.1 (G), R17.2
unnamed: Q3.1 (G), R18.2
unnamed: Q4.1 (G), R19.2
unnamed: Q5.1 (G), R20.2
unnamed: Q6.1 (G), R21.2
unnamed: Q7.1 (G), R22.2
unnamed: Q8.1 (G), R23.2
unnamed: Q9.1 (G), R24.2
unnamed: Q10.1 (G), R25.2
unnamed: R15.1, U4.25 (EXTCLK)

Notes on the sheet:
I2C → PWM
A string of 6x LEDs is 6.4Vf @ 0.3A
I2C Addr: 0x40
LED Enable
LED Driver
LED Sticks

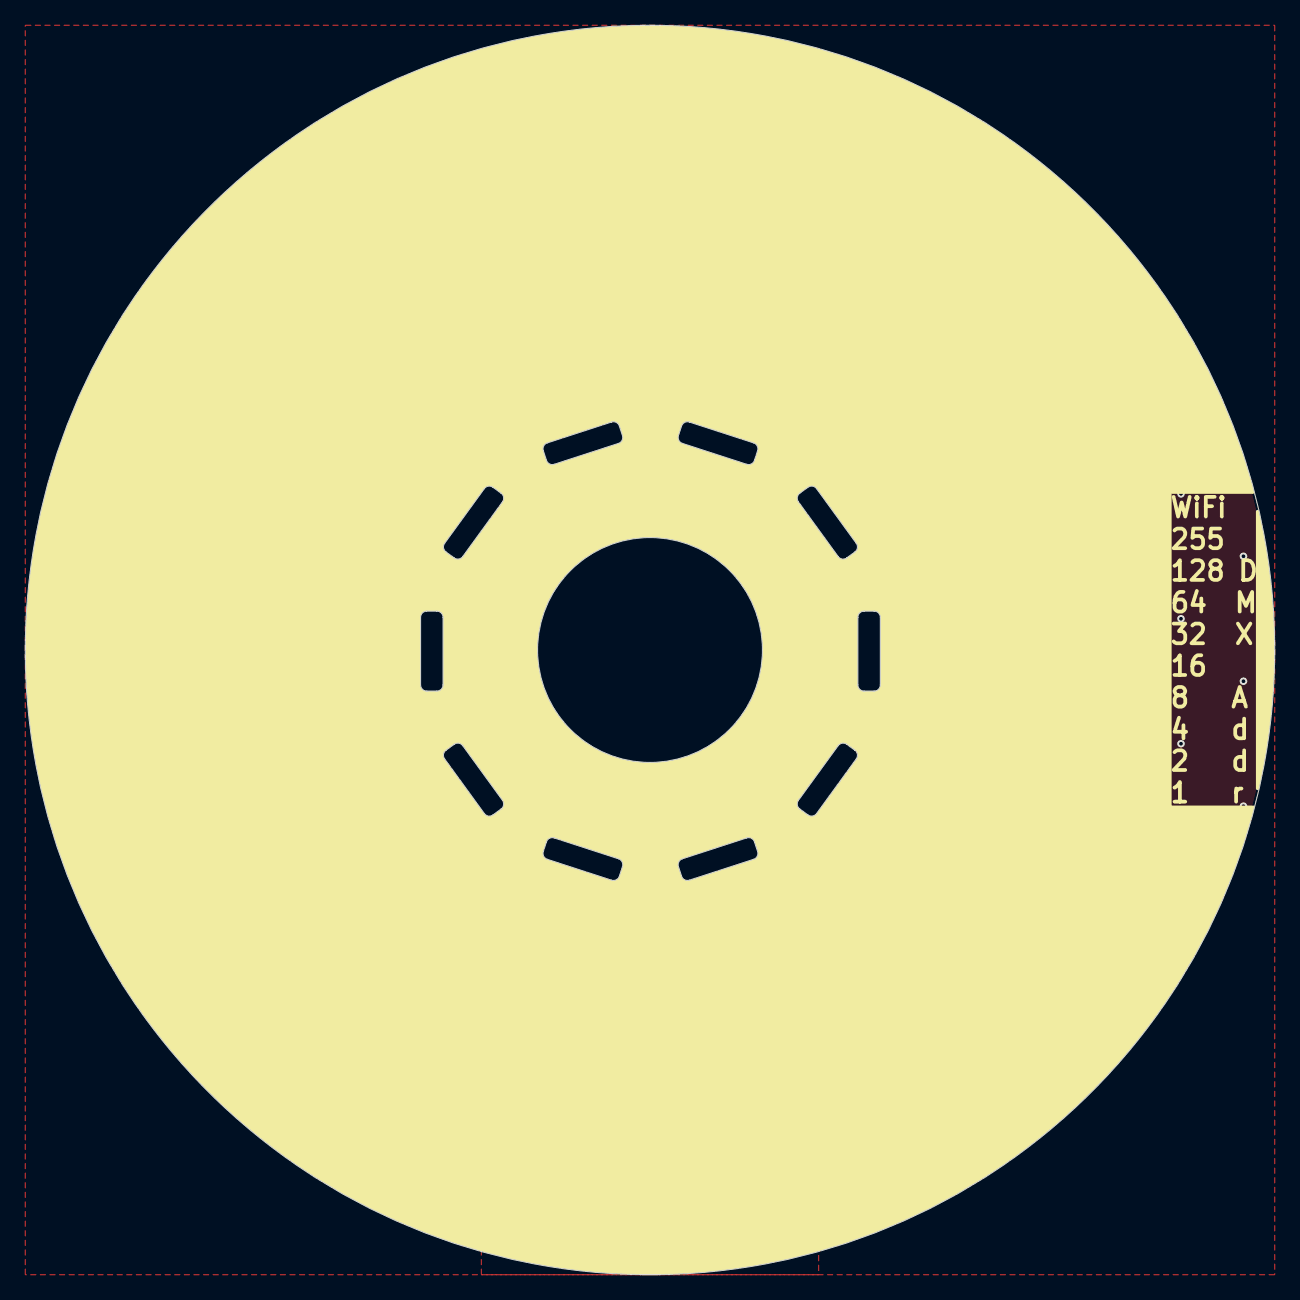
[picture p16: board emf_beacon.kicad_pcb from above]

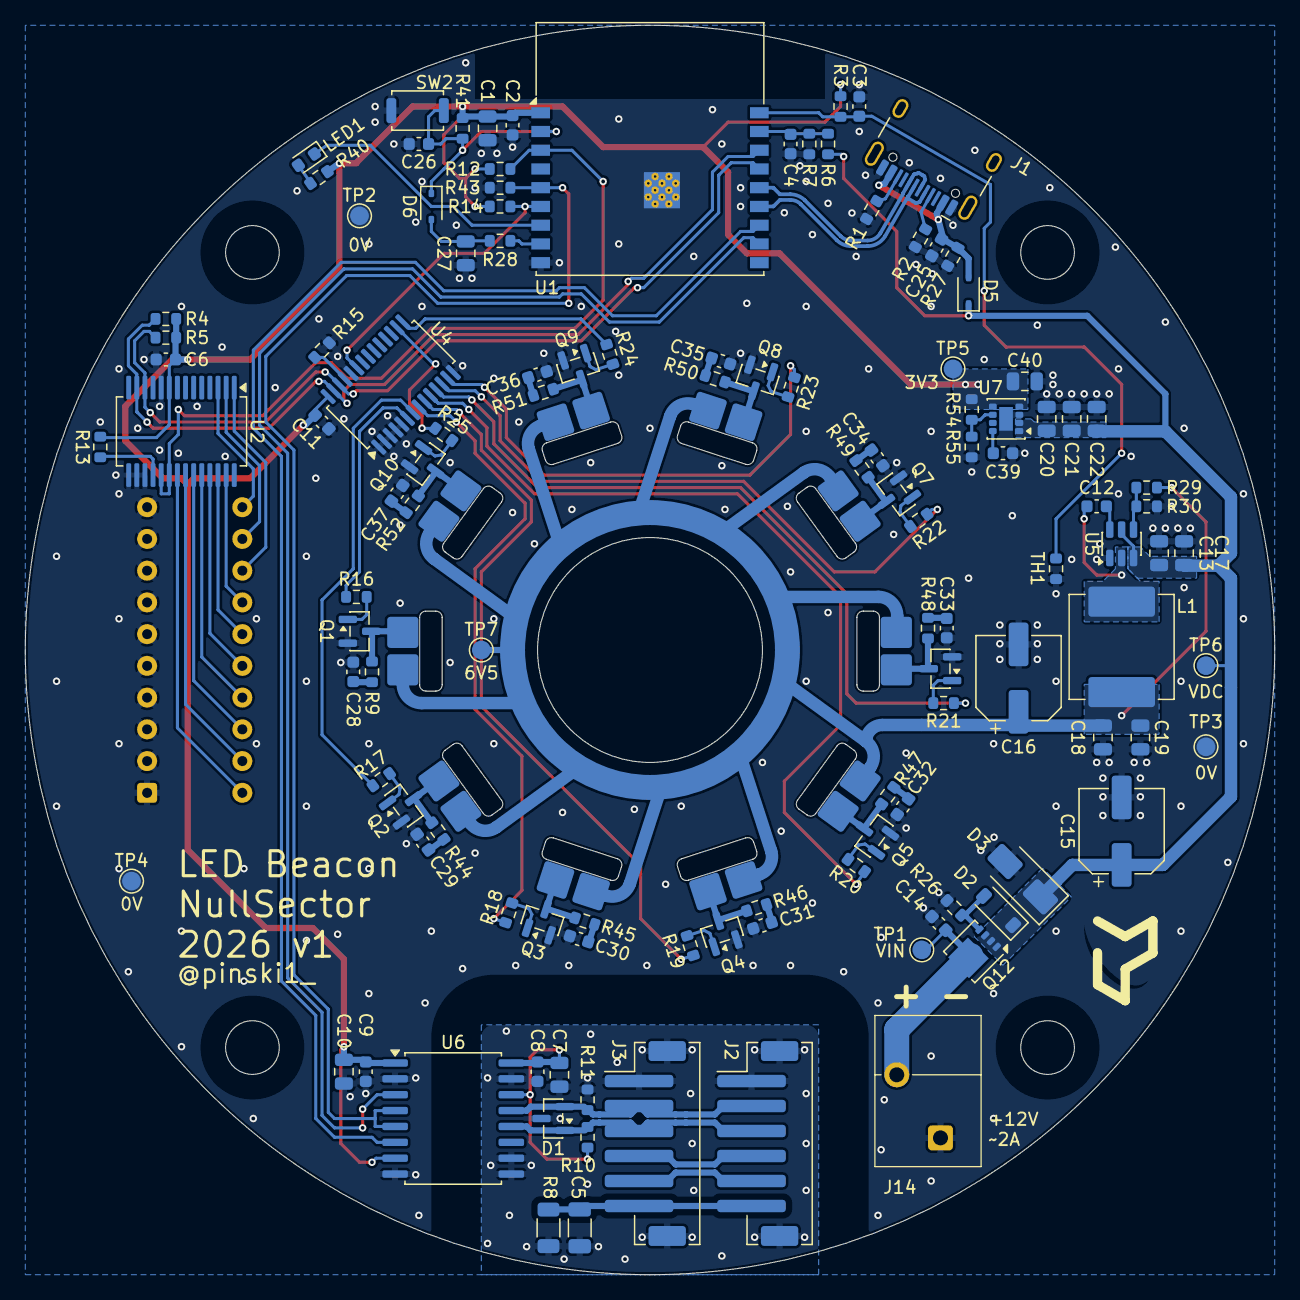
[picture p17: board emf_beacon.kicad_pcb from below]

Board: 2 copper layers, 100.0 x 100.0 mm, 133 parts (128 on the bottom side), 89 nets.

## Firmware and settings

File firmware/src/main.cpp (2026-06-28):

#include <Arduino.h>
#include <Wire.h>
#include <Adafruit_PWMServoDriver.h>
#include <Adafruit_MCP23X17.h>
#include <esp_dmx.h>
#include <WiFi.h>
#include <ESPAsyncWebServer.h>
#include <AsyncTCP.h>

// OTA?

/** Settings **/
const uint32_t led_count = 10;
const uint32_t slot_count = led_count * 2;  // 2 slots per LED
const uint32_t ctrl_loop = 2500;  // control loop duration in ms
const uint32_t hold_last = 4000;  // how long to keep last value in ms
const int32_t warning_temp = 500000;  // temp to disable LEDs in millicelcius
const int32_t warning_volts = 6000;  // voltage to disable LEDs in millivolts
const int wifi_channel = 1;
const char* wifi_ssid = "LED_Beacon_Status";
const char* wifi_pass = "password123";

/** Pin Map **/
#define PIN_TEMP_MON  (0)
#define PIN_VCC_MON   (1)
#define PIN_SDA       (2)
#define PIN_SCL       (3)
#define PIN_I2C_INT   (4)
#define PIN_WIFI_EN   (5)
#define PIN_DMX_EN    (6)
#define PIN_LED_OE    (7)
#define PIN_STATE_LED (8)
#define PIN_DMX_RX   (20)
#define PIN_DMX_TX   (21)

/** Hardware instantiations  **/
Adafruit_PWMServoDriver leds = Adafruit_PWMServoDriver(0x40);
Adafruit_MCP23X17 mcp;
hw_timer_t *led_timer = NULL;
dmx_port_t dmx_num = DMX_NUM_1;
AsyncWebServer server(80);
// OTA
uint32_t last_ctrl_update = 0x00;
uint32_t last_valid_dmx;
int32_t current_temp = 0x00, min_temp, max_temp;
uint32_t current_volts = 0x00, min_volts, max_volts;
uint32_t current_uptime = 0x00;
uint32_t dmx_address = 0x00;
uint8_t dmx_data[slot_count] = {0x00};
bool wifi_enable = false;
uint32_t test_pattern_id = 0;
uint8_t test_pattern_cntr = 0x00;
uint16_t led_brightness[led_count] = {0x00};
uint32_t led_half_period[led_count] = {0x00};
volatile uint32_t led_strobe_cnt[led_count] = {0x00};
volatile bool led_state[led_count] = {false};
volatile bool led_update_req[led_count] = {false};
bool wifi_ap_active = false;

// put function declarations here:
int32_t get_temp(void);
uint32_t get_volts(void);
uint16_t map_led_brightness(uint8_t);
uint32_t map_led_period(uint8_t);
void onTimer(void);
String processor(const String&);

char init_string[] = "\r\nLED Beacon\r\nCompiled on " __DATE__ " " __TIME__ "\r\n";

const char index_html[] PROGMEM = R"rawliteral(
<!DOCTYPE html>
<html>
<head>
  <meta name="viewport" content="width=device-width, initial-scale=1">
  <meta charset="UTF-8">
  <style>
    :root { --bg: #121212; --card: #1e1e1e; --text: #e0e0e0; --accent: #00e676; --dim: #888; }
    body { font-family: sans-serif; background: var(--bg); color: var(--text); margin: 0; padding: 20px; }
    header { text-align: center; margin-bottom: 30px; border-bottom: 1px solid #333; padding-bottom: 10px; }
    .grid { display: flex; flex-wrap: wrap; gap: 15px; max-width: 900px; margin: auto; }
    .card { background: var(--card); padding: 20px; border-radius: 16px; flex: 1 1 calc(50%% - 30px); min-width: 280px; border: 1px solid #2a2a2a; text-align: center; }
    .card h3 { margin: 0 0 12px 0; font-size: 0.85rem; text-transform: uppercase; color: var(--dim); display: flex; justify-content: center; align-items: center; gap: 8px; }
    .val { font-size: 2.2rem; font-weight: 700; color: var(--accent); margin-bottom: 8px; }
    .stats { font-size: 0.85rem; color: var(--dim); display: flex; justify-content: space-around; border-top: 1px solid #2a2a2a; padding-top: 10px; margin-top: 5px; }
    .system-list { text-align: left; display: inline-block; font-size: 0.85rem; line-height: 1.6; }
    .stat-label { color: #555; margin-right: 4px; }
    .btn-group { display: grid; grid-template-columns: repeat(3, 1fr); gap: 8px; margin-top: 10px; }
    .btn { background: #2a2a2a; color: var(--text); border: 1px solid #444; padding: 12px 6px; border-radius: 8px; font-weight: bold; cursor: pointer; transition: 0.2s; font-size: 0.85rem; }
    .btn:hover { background: #3a3a3a; border-color: var(--accent); }
    .btn.active { background: var(--accent); color: #000; border-color: var(--accent); }
  </style>
</head>
<body>
  <header><h1 style="margin:0; font-size: 1.5rem;">LED Beacon</h1></header>
  <div class="grid">
    <div class="card">
      <h3>📟 DMX Address</h3>
      <div class="val">%DMX_ADDR%</div>
      <div class="stats"><span><span class="stat-label">Last:</span>%LAST_DMX%</span></div>
    </div>
    <div class="card">
      <h3>⚡ Voltage</h3>
      <div class="val">%VOLT%</div>
      <div class="stats">
        <span><span class="stat-label">Min:</span>%VOLT_MIN%</span>
        <span><span class="stat-label">Max:</span>%VOLT_MAX%</span>
      </div>
    </div>
    <div class="card">
      <h3>🌡️ Temperature</h3>
      <div class="val">%TEMP%</div>
      <div class="stats">
        <span><span class="stat-label">Min:</span>%TEMP_MIN%</span>
        <span><span class="stat-label">Max:</span>%TEMP_MAX%</span>
      </div>
    </div>
    <div class="card">
      <h3>⚙️ System</h3>
      <div class="system-list">
        <div><span class="stat-label">Uptime:</span> %UPTIME%</div>
        <div><span class="stat-label">Heap Free:</span> %HEAP_FREE%</div>
        <div><span class="stat-label">Heap Min:</span> %HEAP_MIN%</div>
        <div><span class="stat-label">Stack Free:</span> %STACK_FREE%</div>
        <div><span class="stat-label">Reset:</span> %RESET_REASON%</div>
        <div><span class="stat-label">Build:</span> %BUILD%</div>
      </div>
    </div>
    <div class="card">
      <h3>🧪 Test Patterns</h3>
      <div class="btn-group">
        <button class="btn %TEST_STATE_0%" onclick="setPattern(0, this)">DMX</button>
        <button class="btn %TEST_STATE_1%" onclick="setPattern(1, this)">Breathing</button>
        <button class="btn %TEST_STATE_2%" onclick="setPattern(2, this)">Strobe</button>
      </div>
    </div>
  </div>

  <script>
    function setPattern(id, btn) {
      fetch('/set_pattern?id=' + id)
        .then(response => {
          if (response.ok) {
            document.querySelectorAll('.btn').forEach(b => b.classList.remove('active'));
            btn.classList.add('active');
          }
        })
        .catch(err => console.error('Error sending test command:', err));
    }
  </script>
</body>
</html>
)rawliteral";

void setup(void) {
  delay(2000);

  // init Serial
  Serial.begin(115200);
  Serial.write(init_string);

  // init GPIO
  pinMode(PIN_I2C_INT, INPUT);
  pinMode(PIN_LED_OE, OUTPUT);
  pinMode(PIN_DMX_EN, OUTPUT);
  pinMode(PIN_WIFI_EN, INPUT_PULLUP);
  pinMode(PIN_STATE_LED, OUTPUT);
  digitalWrite(PIN_LED_OE, HIGH);  // disable LEDs
  digitalWrite(PIN_DMX_EN, LOW);
  digitalWrite(PIN_STATE_LED, LOW);
  analogSetAttenuation(ADC_11db);
  Serial.println("GPIO initialised...");

  // init Timer
  led_timer = timerBegin(1, 80, true);  // 80Mhz/80 = 1M ticks/sec for 1us resolution
  timerAttachInterrupt(led_timer, &onTimer, true);
  timerAlarmWrite(led_timer, 1000, true);  // trigger every 1000us
  timerAlarmEnable(led_timer);
  Serial.println("Timer initialised...");

  // init I2C
  Wire.begin(PIN_SDA, PIN_SCL);
  Wire.setClock(800000);  // MCP23017 can't do 1MHz unless it's powered from 5V
  Serial.println("I²C initialised...");

  /*
  uint8_t error;
  Serial.println("\r\nScanning for I²C devices...");
  for (uint8_t address = 1; address < 127; address++) {
    Wire.beginTransmission(address);
    error = Wire.endTransmission();

    if (error == 0) {
      Serial.print("I²C device found at 0x");
      if (address < 0x10) Serial.print("0");
      Serial.println(address, HEX);
    } else if (error == 4) {
      Serial.print("Unknown error at 0x");
      if (address < 0x10) Serial.print("0");
      Serial.println(address, HEX);
    }
  }
  Serial.println("Finished scanning for I²C devices!\r\n");
  */

  // init MCP23017
  mcp.begin_I2C(0x20, &Wire);
  mcp.setupInterrupts(true, true, LOW);
  for (int i = 0; i < 16; i++) {
    mcp.pinMode(i, INPUT_PULLUP);
    if (i == 7 || i > 9) continue;  // only configures 0→6 & 8→9
    mcp.setupInterruptPin(i, CHANGE);
  }
  Serial.println("MCP23017 initialised...");

  // init PCA9685
  leds.begin();
  leds.setPWMFreq(1000);
  leds.setOutputMode(true);  // LEDs driven by external NMOS
  for (int i = 0; i < led_count; i++) leds.setPWM(i, 0x000, 0x1000);  // sets LED[i]_OFF_H bit
  delay(1);  // takes a PWM cycle to update
  digitalWrite(PIN_LED_OE, LOW);  // enable LEDs!
  Serial.println("PCA9685 initialised...");

  // init DMX
  dmx_config_t config = DMX_CONFIG_DEFAULT;
  static dmx_personality_t personalities[] {
    {20, "10-Light Mode"}  // 20 slots, custom name
  };
  int personality_count = 1;
  dmx_driver_install(dmx_num, &config, personalities, personality_count);
  dmx_set_pin(dmx_num, PIN_DMX_TX, PIN_DMX_RX, PIN_DMX_EN);
  Serial.println("DMX initialised...");

  // init Watchdog

  // init WiFi
  wifi_ap_active = false;

  server.on("/", HTTP_GET, [](AsyncWebServerRequest *request) {
    request->send(200, "text/html", index_html, processor);
    Serial.println("Serving webpage...");
  });
  server.on("/set_pattern", HTTP_GET, [](AsyncWebServerRequest *request) {
    if (request->hasParam("id")) {
      test_pattern_id = request->getParam("id")->value().toInt();
      request->send(200, "text/plain", "OK");
  } else {
    request->send(400, "text/plain", "Bad Request");
  }
  });
  WiFi.persistent(false);
  WiFi.mode(WIFI_OFF);

  // init OTA

  // set starting min & max
  current_temp = get_temp();
  min_temp = current_temp;
  max_temp = current_temp;
  current_volts = get_volts();
  min_volts = current_volts;
  max_volts = current_volts;

  Serial.println("Setup complete!\r\nStarting loop...\r\n");
  test_pattern_id = 0;
}

void loop(void) {
  // Get DMX packet and update LEDs
  dmx_packet_t packet;
  if (dmx_receive(dmx_num, &packet, 0)) {
    if (!packet.err) {
      uint32_t slot_max = min(512 - dmx_address + 1, slot_count);  // check to see how many valid slots are left
      dmx_read_offset(dmx_num, dmx_address, dmx_data, slot_max);
      memset(&dmx_data[slot_max], 0x00, slot_count - slot_max);  // zero out the invalid slots
      last_valid_dmx = millis();
      // dmxSignalLost = false;

      uint16_t new_brightness;
      uint32_t new_half_period;
      for (int i = 0; i < led_count; i++) {
        new_brightness = map_led_brightness(dmx_data[i]);
        if (led_brightness[i] != new_brightness) {
          led_brightness[i] = new_brightness;
          led_update_req[i] = true;
        }

        new_half_period = map_led_period(dmx_data[i + led_count]);
        if (led_half_period[i] != new_half_period) {
          led_half_period[i] = new_half_period;
          if (new_half_period == 0) {
            // force an update if LED is to be fully on
            led_update_req[i] = true;
          }
        }
      }
    }
  }

  delay(1);

  // handle DMX timeout
  if (millis() - last_valid_dmx > hold_last && test_pattern_id == 0) {
    for (int i = 0; i < led_count; i++) {
      if (led_brightness[i] != 0x00) {
        led_brightness[i] = 0x00;
        led_half_period[i] = 0x00;
        led_update_req[i] = true;
        led_state[i] = true;
      }
    }
  }

  // inject test pattern
  if (test_pattern_id > 0) {
    // animation loop
      uint8_t test_brightness;
      uint16_t new_brightness;
      uint32_t new_half_period;
      switch (test_pattern_id) {
        case 1:  // breathing
          test_brightness = (test_pattern_cntr < 128) ? (test_pattern_cntr << 1) : (~test_pattern_cntr << 1);
          new_brightness = map_led_brightness(test_brightness);

          for (int i = 0; i < led_count; i++) {
            led_brightness[i] = new_brightness;
            led_update_req[i] = true;
          }
          break;
        case 2:  // strobes
          new_brightness = map_led_brightness(128);
          new_half_period = map_led_period(128);

          for (int i = 0; i < led_count; i++) {
            if (led_brightness[i] != new_brightness && led_half_period[i] !=  new_half_period) {
              led_brightness[i] = new_brightness;
              led_half_period[i] = new_half_period;
              led_update_req[i] = true;
            }
          }
          break;
        default:
          break;
      }
      test_pattern_cntr++;
    } else {
      test_pattern_cntr = 0x00;
    }


  // update LEDs
  for (int i = 0; i < led_count; i++) {
    if (led_update_req[i]) {
      led_update_req[i] = false;
      uint16_t on_time = 410 * i;
      uint16_t off_time;
      if (led_state[i] && led_brightness[i] > 0x00) {
        if (led_brightness[i] == 4095) {
          // special PCA9685 'always on' mode
          on_time = 4096;
          off_time = 0;
        } else {
          off_time = (on_time + led_brightness[i]) % 4096;
        }
      } else {
        // 'always off' mode
        off_time = on_time;
      }
      leds.setPWM(i, on_time, off_time);
    }
  }

  // update control loop
  if (millis() - last_ctrl_update >= ctrl_loop) {
    last_ctrl_update = millis();

    // get current VCC in and temperature
    current_volts = get_volts();
    current_temp = get_temp();

    // update min/max temp/volts
    if (current_temp > -50000 && current_temp < 150000) {
      // but only if temp is between -50°C and 150°C
      min_temp = min(min_temp, current_temp);
      max_temp = max(max_temp, current_temp);
    }
    min_volts = min(min_volts, current_volts);
    max_volts = max(max_volts, current_volts);

    // dealing with excessive temp
    if (current_temp >= warning_temp) {
      digitalWrite(PIN_LED_OE, HIGH);  // disable LEDs while too hot!
    } else if (current_temp <= (warning_temp - 5000)) {
      digitalWrite(PIN_LED_OE, LOW);  // enable LEDs now it's cooler
    }

    // not sure what actions to take on over voltage

    // dealing with under voltage
    if (current_volts <= warning_volts) {
      digitalWrite(PIN_LED_OE, HIGH);  // disable LEDs if input voltage is too low!
    } else if (current_volts <= (warning_volts + 3000)) {
      digitalWrite(PIN_LED_OE, LOW);  // enable LEDs now input voltage is higher
    }

    current_uptime = esp_timer_get_time() / 1000000;
    // check MCP and update DMX address & WiFi AP
    uint16_t dmx_adr_switches, wifi_en_switches;
    uint16_t mcp_pin_values = ~mcp.readGPIOAB();  // read and flip switch states from ACTIVE_LOW to ACTIVE_HIGH

    Serial.print("MCP reads: 0b");
    Serial.println(mcp_pin_values, BIN);

    // keep 0→6 & 8→9 and concatenate to remove 7
    dmx_adr_switches = (mcp_pin_values & 0x7F) | ((mcp_pin_values & 0x0300) >> 1);
    dmx_address = dmx_adr_switches;  // save DMX address

    wifi_enable = (mcp_pin_values >> 10) & 0x01;

    // enable/disable WiFi AP
    if (wifi_enable && !wifi_ap_active) {
      WiFi.persistent(false);
      WiFi.mode(WIFI_AP);
      WiFi.softAP(wifi_ssid, wifi_pass, wifi_channel);
      wifi_ap_active = true;
      server.begin();
      Serial.print("Enabling WiFi AP with IP: ");
      Serial.println(WiFi.softAPIP());
    } else if (!wifi_enable && wifi_ap_active) {
      server.end();
      WiFi.persistent(false);
      WiFi.softAPdisconnect(true);
      WiFi.mode(WIFI_OFF);
      wifi_ap_active = false;
      test_pattern_id = 0;  // set back to DMX mode
      Serial.println("Disabling WiFi...");
    }

    // update USB status
  }
}

void IRAM_ATTR onTimer(void) {
  for (int i = 0; i < 10; i++) {
    if (led_half_period[i] == 0) {
      if (!led_state[i]) {
        led_state[i] = true;
        led_update_req[i] = true;
      }
      led_strobe_cnt[i] = 0;  // Keep counter reset
      continue;
    }

    led_strobe_cnt[i]++;
    if (led_strobe_cnt[i] >= led_half_period[i]) {
      led_strobe_cnt[i] = 0;
      led_state[i] = !led_state[i];
      led_update_req[i] = true;
    }
  }
}

/** 8bit to 12bit gamma look up table
 * uint16_t = (uint8_t / (2^8 - 1)) ^ 2.8 * (2^12 - 2)
 */
static const uint16_t gamma12_table[] PROGMEM = {
    0, 0, 0, 0, 0, 0, 0, 0, 0, 0, 0, 1, 1, 1, 1, 1,
    2, 2, 2, 3, 3, 4, 4, 5, 5, 6, 7, 8, 8, 9, 10, 11,
    12, 13, 15, 16, 17, 18, 20, 21, 23, 25, 26, 28, 30, 32, 34, 36,
    38, 40, 43, 45, 48, 50, 53, 56, 59, 62, 65, 68, 71, 75, 78, 82,
    85, 89, 93, 97, 101, 105, 110, 114, 119, 123, 128, 133, 138, 143, 149, 154,
    159, 165, 171, 177, 183, 189, 195, 202, 208, 215, 222, 229, 236, 243, 250, 258,
    266, 273, 281, 290, 298, 306, 315, 324, 332, 341, 351, 360, 369, 379, 389, 399,
    409, 419, 430, 440, 451, 462, 473, 485, 496, 508, 520, 532, 544, 556, 569, 582,
    594, 608, 621, 634, 648, 662, 676, 690, 704, 719, 734, 749, 764, 779, 795, 811,
    827, 843, 859, 876, 893, 910, 927, 944, 962, 980, 998, 1016, 1034, 1053, 1072, 1091,
    1110, 1130, 1150, 1170, 1190, 1210, 1231, 1252, 1273, 1294, 1316, 1338, 1360, 1382, 1404, 1427,
    1450, 1473, 1497, 1520, 1544, 1568, 1593, 1617, 1642, 1667, 1693, 1718, 1744, 1770, 1797, 1823,
    1850, 1877, 1905, 1932, 1960, 1988, 2017, 2045, 2074, 2103, 2133, 2162, 2192, 2223, 2253, 2284,
    2315, 2346, 2378, 2410, 2442, 2474, 2507, 2540, 2573, 2606, 2640, 2674, 2708, 2743, 2778, 2813,
    2849, 2884, 2920, 2957, 2993, 3030, 3067, 3105, 3143, 3181, 3219, 3258, 3297, 3336, 3376, 3416,
    3456, 3496, 3537, 3578, 3619, 3661, 3703, 3745, 3788, 3831, 3874, 3917, 3961, 4005, 4049, 4094
};

uint16_t map_led_brightness(uint8_t brightness) {
  return gamma12_table[brightness];
}

// This table stores the ms delay between TOGGLES (Half-Period)
static const uint32_t strobe_half_period_table[] PROGMEM = {
    0, 2500, 2415, 2336, 2261, 2191, 2126, 2064, 2006, 1951, 1899, 1850, 1803, 1759, 1716, 1676,
    1637, 1600, 1565, 1531, 1499, 1468, 1438, 1409, 1382, 1355, 1329, 1305, 1281, 1258, 1236, 1214,
    1194, 1174, 1154, 1136, 1118, 1100, 1083, 1067, 1051, 1035, 1020, 1006, 992, 978, 965, 952,
    939, 927, 915, 903, 892, 881, 870, 860, 850, 840, 830, 821, 811, 802, 793, 785,
    776, 768, 760, 752, 745, 737, 730, 723, 716, 709, 702, 696, 689, 683, 677, 671,
    665, 659, 653, 647, 642, 636, 631, 626, 621, 616, 611, 606, 601, 597, 592, 588,
    583, 579, 575, 571, 566, 562, 558, 554, 550, 547, 543, 539, 536, 532, 529, 525,
    522, 518, 515, 512, 508, 505, 502, 499, 496, 493, 490, 487, 484, 481, 478, 475,
    472, 470, 467, 464, 462, 459, 456, 454, 451, 449, 446, 444, 441, 439, 437, 434,
    432, 430, 427, 425, 423, 421, 418, 416, 414, 412, 410, 408, 406, 404, 402, 400,
    398, 396, 394, 392, 390, 388, 386, 384, 383, 381, 379, 377, 376, 374, 372, 371,
    369, 367, 366, 364, 362, 361, 359, 358, 356, 355, 353, 352, 350, 349, 348, 346,
    345, 343, 342, 341, 339, 338, 337, 335, 334, 333, 331, 330, 329, 328, 326, 325,
    324, 323, 322, 321, 319, 318, 317, 316, 315, 314, 313, 312, 311, 310, 309, 308,
    306, 305, 304, 303, 302, 301, 300, 299, 298, 297, 296, 295, 294, 293, 292, 291,
    290, 289, 288, 287, 286, 285, 284, 283, 282, 281, 281, 280, 279, 278, 277, 16
};

uint32_t map_led_period(uint8_t period) {

  // FILL ME OUT!
  // freq: 1-30Hz, 0.289-16.667Hz
  // msg: 0 = solid, 1 = slow, 255 = fast
  // DMX 1   = 5.000 seconds
  // DMX 255 = 0.033 seconds

  return strobe_half_period_table[period];
}

String processor(const String& var) {
  if (var == "DMX_ADDR") return String(dmx_address);
  if (var == "LAST_DMX") return String((millis() - last_valid_dmx)/1000) + "s ago";
  if (var == "VOLT")     return String(((float)current_volts/1000), 2) + "V";
  if (var == "VOLT_MIN") return String(((float)min_volts/1000), 2) + "V";
  if (var == "VOLT_MAX") return String(((float)max_volts/1000), 2) + "V";
  if (var == "TEMP")     return String(((float)current_temp/1000), 2) + "&deg;C";
  if (var == "TEMP_MIN") return String(((float)min_temp/1000), 2) + "&deg;C";
  if (var == "TEMP_MAX") return String(((float)max_temp/1000), 2) + "&deg;C";
  if (var == "BUILD")    return String(__DATE__) + " " + String(__TIME__);
  if (var == "HEAP_FREE") return String(ESP.getFreeHeap() / 1024.0, 1) + " KB";
  if (var == "HEAP_MIN")  return String(ESP.getMinFreeHeap() / 1024.0, 1) + " KB";
  if (var == "STACK_FREE") return String(uxTaskGetStackHighWaterMark(NULL)) + " bytes";
  if (var == "UPTIME") {
    uint32_t t = current_uptime;
    uint32_t s = t % 60;
    uint32_t m = (t / 60) % 60;
    uint32_t h = (t / 3600) % 24;
    uint32_t d = t / 86400;

    String res = "";
    if (d > 0) res += String(d) + "d ";
    if (h > 0 || d > 0) res += String(h) + "h ";
    if (m > 0 || h > 0 || d > 0) res += String(m) + "m ";
    res += String(s) + "s";
    return res;
  }
  if (var == "RESET_REASON") {
    esp_reset_reason_t reason = esp_reset_reason();
    switch (reason) {
      case ESP_RST_POWERON: return "Power On";
      case ESP_RST_EXT:     return "External Pin";
      case ESP_RST_SW:      return "Software Reset";
      case ESP_RST_PANIC:   return "Exception/Crash";
      case ESP_RST_INT_WDT: return "Interrupt Watchdog";
      case ESP_RST_TASK_WDT: return "Task Watchdog";
      case ESP_RST_DEEPSLEEP: return "Deep Sleep Wake";
      case ESP_RST_BROWNOUT: return "Brownout (Power Dip)";
      default:               return "Unknown";
    }
  }
  if (var == "TEST_STATE_0") return (test_pattern_id == 0) ? "active" : "";
  if (var == "TEST_STATE_1") return (test_pattern_id == 1) ? "active" : "";
  if (var == "TEST_STATE_2") return (test_pattern_id == 2) ? "active" : "";
  return String();
}

/** 
 * Lookup table for NCP15XH103F03RC 
 * Based on 10k pull-down (to GND) and 12-bit ADC (0-4095)
 * Format: {ADC_Value, Temp_in_C}
 */
struct TempPoint {
    int16_t adc;
    int16_t temp;
};

// LUT for: 3.3V -> 10k Resistor -> IO0 -> Thermistor + 1uF -> GND
const TempPoint lut[] = {
    {3115, -10}, {2703, 0},  {2263, 10}, {1850, 20},
    {1485, 30},  {1176, 40}, {924, 50},  {724, 60},
    {568, 70},   {449, 80},  {356, 90},  {286, 100}
};
const size_t LUT_SIZE = sizeof(lut) / sizeof(lut[0]);
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

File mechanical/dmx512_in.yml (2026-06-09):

metadata:
  title: DMX512 Input
  revisions:
    "1":
        name: Robert K
        date: 2026-05-12
        changelog: Initial Version
  template:
    name: din-6771
    sheetsize: A4

connectors:
  X:
    type: XLR 5way
    subtype: Pins
    manufacturer: '<a href="https://www.rean-connectors.com/en">Neutrik REAN</a>'
    mpn: '<a href="https://www.rean-connectors.com/en/product/rrx5m-z">RRX5M-Z-002-0</a>'
    pinlabels: [GND,DMX+,DMX-,AUX-,AUX+,SHIELD]
    show_pincount: false
    #image:
    additional_components:
      -
        type: heatshrink
        subtype: 3.2mm dia, 10mm long
        qty_multiplier: populated

  J:
    type: JST PH 6way
    subtype: Housing
    pinlabels: [GND,DMX+,DMX-,AUX-,AUX+,SHIELD]
    manufacturer: '<a href="https://www.jst-mfg.com/index_e.php">JST</a>'
    mpn: '<a href="https://www.jst-mfg.com/product/index.php?series=199">PHR-6</a>'
    #image:
    additional_components:
      - 
        type: Crimp
        subtype: JST PH, 30-24 AWG
        qty_multiplier: populated
        manufacturer: '<a href="https://www.jst-mfg.com/index_e.php">JST</a>'
        mpn: '<a href="https://www.jst-mfg.com/product/index.php?series=199">SPH-002T-P0.5S</a>'

cables:
  W:
    category: bundle
    gauge: 26 AWG
    length: 10 cm
    colors: [BK,RD,WH,YE,OG,GN]
    #notes: "Twist wires 2 &amp; 3 together.\nTwist wires 4 &amp; 5 together."

connections:
  -
   - X: [1-6]
   - W: [1-6]
   - J: [1-6]

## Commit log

2026-04-20 inital board files
    [art-net.kicad_sch, ctrl.kicad_sch, dmx512.kicad_sch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]
2026-04-21 removing 'home' from filenames
    [emf_beacon.kicad_pcb, emf_beacon.kicad_sch]
2026-04-21 adding ESP32 and PSU options
    [ctrl.kicad_sch, emf_beacon.kicad_sch, power.kicad_sch]
2026-04-21 docs: auto-generate schematic PDF
2026-04-21 removed Art-Net
    [ctrl.kicad_sch, dmx512.kicad_sch, emf_beacon.kicad_pcb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]
2026-04-22 clean up
    [ctrl.kicad_sch, dmx512.kicad_sch, emf_beacon.kicad_pcb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]
2026-04-22 updating readme
    [ctrl.kicad_sch, emf_beacon.kicad_pcb]
2026-04-23 adding 3D model of 3D printed beacon base
    [3d Printed Base.step]
2026-04-24 removing I2C scanner
2026-04-25 improving voltage and temperature calcs
2026-04-26 updating thermistor and GPIO expander
    [ctrl.kicad_sch, dmx512.kicad_sch, emf_beacon.kicad_pcb]
2026-04-27 adding LED bightness functionality
2026-04-27 adding snubbers, starting placement
    [ctrl.kicad_sch, dmx512.kicad_sch, emf_beacon.kicad_pcb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]
2026-04-30 updating PSUs
    [ctrl.kicad_sch, dmx512.kicad_sch, emf_beacon.kicad_pcb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]
2026-04-30 removing art-net.kicad_sch
    [art-net.kicad_sch]
2026-04-30 some jlc cleanup
    [ctrl.kicad_sch, dmx512.kicad_sch, emf_beacon.kicad_pcb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]
2026-05-07 tweaking lcsc part numbers
    [ctrl.kicad_sch, dmx512.kicad_sch, emf_beacon.kicad_pcb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]
2026-05-12 docs: auto-generate schematic PDF, 3D model, and rear render
    [emf_beacon_3d.step]
2026-05-12 Adding wiring drawings for XLR pigtails
2026-05-13 general schematic and PCB clean
    [ctrl.kicad_sch, dmx512.kicad_sch, emf_beacon.kicad_pcb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]
2026-05-21 sorting button and LED
    [ctrl.kicad_sch, dmx512.kicad_sch, emf_beacon.kicad_pcb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]
2026-05-24 starting layout
    [ctrl.kicad_sch, dmx512.kicad_sch, emf_beacon.kicad_pcb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]
2026-05-25 adding DRU for DMX isolation
    [dmx512.kicad_sch, emf_beacon.kicad_pcb]
2026-05-25 more layout and fixing OOS items
    [ctrl.kicad_sch, dmx512.kicad_sch, emf_beacon.kicad_pcb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]
2026-06-02 LEDs connected
    [emf_beacon.kicad_pcb]
2026-06-03 updating DMX TRX and improving silkscreen
    [dmx512.kicad_sch, emf_beacon.kicad_pcb]
2026-06-03 routing VDC
    [emf_beacon.kicad_pcb]
2026-06-03 fixing terminal block pads
    [emf_beacon.kicad_pcb]
2026-06-04 finished USB routing
    [emf_beacon.kicad_pcb]
2026-06-04 finished NTC routing
    [emf_beacon.kicad_pcb]
2026-06-04 ran DRC & DFM checks, looks good
    [emf_beacon.kicad_pcb]
2026-06-05 adding stitching vias
    [emf_beacon.kicad_pcb]
2026-06-05 reviewed LED connections and found a fault
    [leds.kicad_sch]
2026-06-05 unswapped LEDs
    [emf_beacon.kicad_pcb, leds.kicad_sch]
2026-06-05 preparing for release
    [ctrl.kicad_sch, dmx512.kicad_sch, emf_beacon.kicad_pcb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]
2026-06-09 tweaking wiring drawings
    [3D Base v17.step, 3d Printed Base 2.step]
2026-06-09 removing old base files
    [3D Printed Base v17.step, 3d Printed Base 2.step, 3d Printed Base.step]
2026-06-09 adding wiring diagram generator
2026-06-09 chore: auto-generate WireViz PDFs from mechanical/ [skip ci]
2026-06-10 adding svg to pdf for wireviz
2026-06-22 support for high DMX Addresses and LED test pattern
2026-06-28 fixed WiFi AP enable/disable
    [main.cpp]
2026-06-28 LEDs don't flash on boot
2026-10-20 Updating ISR to use `led_count`
